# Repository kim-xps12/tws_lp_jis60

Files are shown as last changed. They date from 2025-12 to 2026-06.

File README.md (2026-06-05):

# tws_lp_jis60

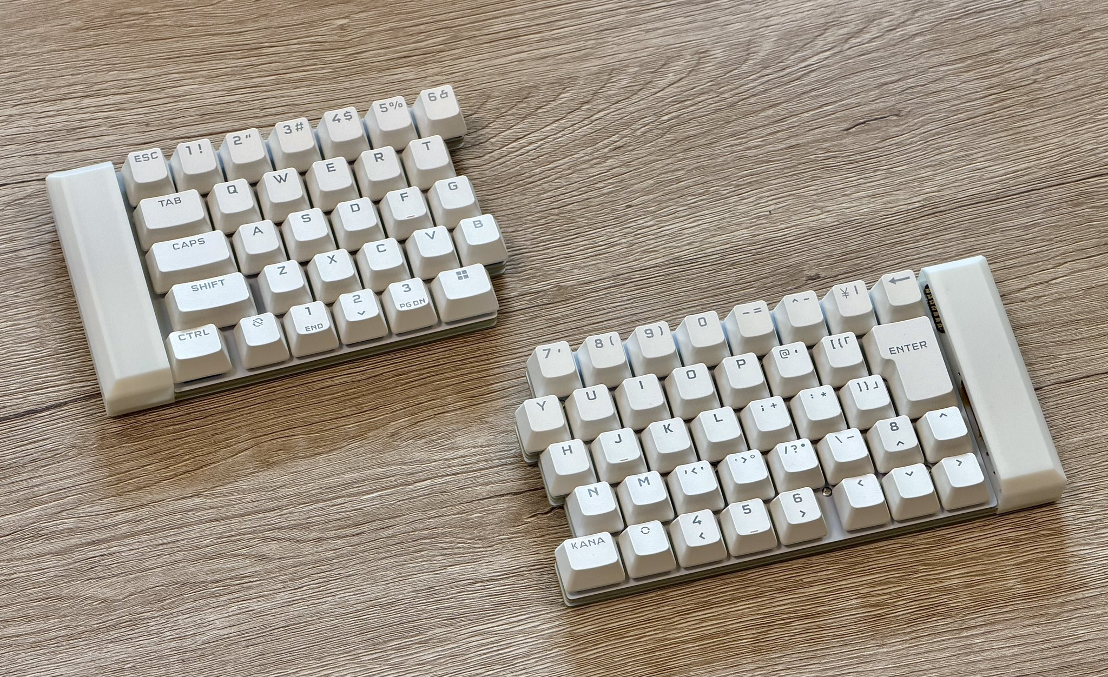
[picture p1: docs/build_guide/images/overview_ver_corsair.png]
完成品の写真


## About

JIS配列・ロープロファイル・完全無線の左右分割60%キーボードです。

## Concept

[sphh jp v2 (a bit keys)](https://abitkeys.com/sphhjp/build_v2.html) のHHKB-likeなJIS配列を分割化したコンセプトを継承し、完全無線化とロープロファイル化を加えた設計です。

- JIS 60%配列（ISOエンター、矢印キー付き）
- 完全無線（PC接続も左右間もBLE）
- Kailh Choc v2 互換ホットスワップ
- PCBサンドイッチ構造
- ZMK Firmware によるキーマップ変更
- XIAO nRF52840 搭載

設計の詳細は設計者の note 記事を参照してください: [JIS配列でロープロファイルな完全無線の左右分割キーボードを作った話](https://note.com/b_sky_lab/n/n9fbacc2c5264)

## How to Build

ビルドガイドは Web 版（[https://b-sky-lab.github.io/tws_lp_jis60/](https://b-sky-lab.github.io/tws_lp_jis60/)）を参照してください。ソースは [docs/build_guide/build_guide.md](docs/build_guide/build_guide.md) です。

ファームウェア（ZMKシールドモジュール）は [b-sky-lab/tws_lp_shield_module](https://github.com/b-sky-lab/tws_lp_shield_module) で管理されています。

## Where to Get

<!-- TODO: Booth頒布開始後にリンクを追加 -->
準備中

## License

このリポジトリは CC-BY-SA-4.0（Creative Commons Attribution-ShareAlike 4.0 International）でライセンスされています．

詳細は [LICENSE](./LICENSE) を参照してください.

### Third-Party Components

本プロジェクトは，以下の第三者ライブラリのコンポーネントを利用しています：

#### 1. OPL_Kicad_Library (CC-BY-SA-4.0)
- fork元: https://github.com/Seeed-Studio/OPL_Kicad_Library
- fork先: https://github.com/kim-xps12/OPL_Kicad_Library
- ライセンス: CC-BY-SA-4.0
- 変更ファイル: `XIAO-nRF52840-DIP.kicad_mod`（DRCシルク警告の修正）
- 利用箇所: [pcb_data/kicad_library/external/OPL_Kicad_Library](pcb_data/kicad_library/external/OPL_Kicad_Library)（submodule）

#### 2. KiCAD_FootPrint (MIT)
- fork元: https://github.com/Salicylic-acid3/KiCAD_FootPrint
- fork先: https://github.com/kim-xps12/KiCAD_FootPrint
- ライセンス: MIT
- 変更ファイル: `Diode_TH_SMD.kicad_mod`（DRCシルク警告の修正）
- 利用箇所: [pcb_data/kicad_library/external/KiCAD_FootPrint](pcb_data/kicad_library/external/KiCAD_FootPrint)（submodule）

#### 3. MX_V2 (MIT)
- fork元: https://github.com/ai03-2725/MX_V2
- 利用ディレクトリ:[custom-library.pretty](pcb_data/kicad_library/custom-library.pretty)
- ライセンス: MIT
- 派生物: `pcb_data/kicad_library/custom-library.pretty/`内のカスタムフットプリント
- 帰属表示: 当該ディレクトリ内の[LICENSE_MX_V2.txt](pcb_data/kicad_library/custom-library.pretty/LICENSE_MX_V2.txt)を参照

### Why CC-BY-SA-4.0？

本作のライセンスがCC-BY-SA-4.0である理由は，PCB設計ファイルにOPL_Kicad_Libraryから改変したフットプリントを組み込んでいるからです．CC-BY-SA-4.0のShareAlike条項により，派生物も同じCC-BY-SA-4.0ライセンスを継承する必要があります．

MITライセンスのコンポーネント（KiCAD_FootPrint，MX_V2）は，適切な帰属表示を維持することでCC-BY-SA-4.0と互換性があります．

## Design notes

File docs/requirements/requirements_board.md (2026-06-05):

# 基板の要件

本書では自作左右分割キーボード`tws_lp_jis60`の基板設計に対して求める要件を列挙する．

## 機械的要件

- キースイッチの数，キー幅，配置の全てをsphh jp v2に準拠すること．
- 基板の外形をsphh jp v2に準拠した形状とすること．すなわち，左手側基板の右辺以外3辺と右手側基板の左辺以外3辺は水平/垂直な線であり，左手側基板の右辺と右手側基板の左辺はそれぞれが噛み合うような階段状の形状が求められる．
- （参考）sphh jp v2公式サイト: https://abitkeys.com/sphhjp/build_v2.html

## 電子回路要件

### キースイッチ

- キースイッチのホットスワップに対応するため，基板にはソケットのみを半田付けで固定すること．
- 対象のキースイッチは，Kailh Choc v2互換を想定すること．

### マイコン

- マイコンにはxiao系の開発ボードを用いること．
  - XIAO nRF52840 を採用（BLE対応・バッテリー管理IC搭載のため）  
- 開発ボードは基板に取り付けること．
  - **実装**: XIAO nRF52840 を基板に直接はんだ付け（着脱不可）
- ボード選定の際には最低限以下を満たすこと．

  - キー数に対して十分な入出力ピンを持つこと
  - 単体でバッテリ管理機能を搭載していること
  - 単体でBluetooth LEによる通信が行えること
  - 接続端子としてUSB Type-Cを有すること

- 上記以外にも基板レイアウト等に対して適切な条件を適宜定めること．

### インジケータ

- キーボードの内部状態（現在のBT接続状態，電池残量など）を示すためのインジケータランプを有すること．
  - **実装**: XIAO nRF52840 オンボードのRGB LED 1個を使用し、[zmk-rgbled-widget](https://github.com/caksoylar/zmk-rgbled-widget) により色と点滅パターンで接続状態・電池残量・レイヤーを表示
- 適切な色のLEDの点灯状態によって上記を示すことを最小要件とする．

### 電源

- 左右の基板にはそれぞれ独立した電源が取り付けられること
- 使用される電力源は乾電池が最も好ましいが，開発難易度に応じてマイコンボードに直接接続できる充電池を用いてもよい．
  - **実装**: リチウムイオンポリマーバッテリーをXIAO nRF52840のBATパッドに直接接続（内蔵充電IC BQ25101で管理）

### 接続方式

- 通常の使用においてホストマシン（PC, スマートフォン等）との接続にはBluetooth LEを用いること．
- 左右間の通信も無線で行うこと．この接続はファームウェアの機能を適切に利用する想定でよい．
- ただし，キーマップ書き換え時にはマイコンボードに搭載されたUSBポートを利用することを想定してもよい．

## ソフトウェア要件

- ファームウェアのベースとしてZMK Firmwareを用いること
- ファームウェア書き換えによってキーマップの変更ができること
- （参考）
    - ZMK Firmware公式ページ: https://zmk.dev/docs

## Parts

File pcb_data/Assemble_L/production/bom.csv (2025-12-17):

Designator | Footprint | Quantity | Value | LCSC Part #
D0-1, D0-2, D0-3, D0-4, D1-0, D1-2, D1-3, D1-4, D2-0, D2-1, D2-3, D2-4, D3-0, D3-1, D3-2, D3-4, D4-0, D4-1, D4-2, D4-3, D5-0, D5-1, D5-2, D5-3, D5-4, D6-0, D6-1, D6-2, D6-3, D6-4, D6-5, DI0, DI1, DI2, DI3, DI4, DI5, DS0, DS1, DS2, DS3, DS4, DS5 | Diode_TH_SMD | 43 | 1N4148W
RC0-1 | Kailh-PG1353-Hotswap-L-1.5U | 1 | SW_Push
RC0-2 | Kailh-PG1353-Hotswap-L-1.75U | 1 | SW_Push
RC0-3 | Kailh-PG1353-Hotswap-L-2U | 1 | SW_Push
RC0-4, RC1-0, RC1-2, RC1-3, RC1-4, RC2-0, RC2-1, RC2-3, RC2-4, RC3-0, RC3-1, RC3-2, RC3-4, RC4-0, RC4-1, RC4-2, RC4-3, RC5-0, RC5-1, RC5-2, RC5-3, RC5-4, RC6-0, RC6-1, RC6-2, RC6-3, RC6-4 | Kailh-PG1353-Hotswap-L-1U | 27 | SW_Push
RC6-5 | Kailh-PG1353-Hotswap-L-1.25U | 1 | SW_Push
U1 | XIAO-nRF52840-DIP | 1 | XIAO-nRF52840

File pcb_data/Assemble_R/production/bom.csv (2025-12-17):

Designator | Footprint | Quantity | Value | LCSC Part #
D0-10, D0-11, D0-12, D0-13, D0-8, D0-9, D1-10, D1-11, D1-12, D1-7, D1-9, D2-10, D2-11, D2-12, D2-13, D2-7, D2-8, D3-11, D3-12, D3-13, D3-7, D3-8, D3-9, D4-10, D4-12, D4-7, D4-8, D4-9, D5-10, D5-11, D5-13, D5-7, D5-8, D5-9, D6-10, D6-11, D6-12, D6-8, D6-9, DI10, DI11, DI12, DI13, DI7, DI8, DI9, DS10, DS11, DS12, DS13, DS7, DS8, DS9 | Diode_TH_SMD | 53 | 1N4148W
RC0-10, RC0-11, RC0-12, RC0-8, RC0-9, RC1-10, RC1-11, RC1-12, RC1-7, RC1-9, RC2-10, RC2-11, RC2-12, RC2-13, RC2-7, RC2-8, RC3-11, RC3-12, RC3-13, RC3-7, RC3-8, RC3-9, RC4-10, RC4-12, RC4-7, RC4-8, RC4-9, RC5-10, RC5-11, RC5-13, RC5-7, RC5-8, RC5-9, RC6-11, RC6-12, RC6-8, RC6-9 | Kailh-PG1353-Hotswap-R-1U | 37 | SW_Push
RC0-13 | Kailh-PG1353-Hotswap-R-1.25U | 1 | SW_Push
RC6-10 | Kailh-PG1353-Hotswap-ISOEnter-R | 1 | SW_Push
U1 | XIAO-nRF52840-DIP | 1 | XIAO-nRF52840

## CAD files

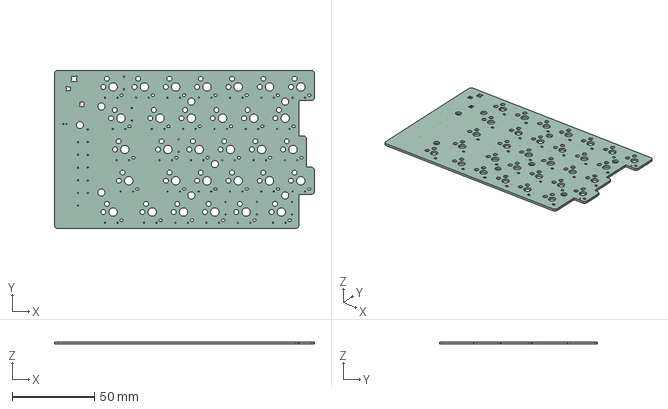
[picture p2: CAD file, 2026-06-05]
pcb_data/Assemble_L/Assemble_L.step
158.4 x 96.4 x 1.51 mm

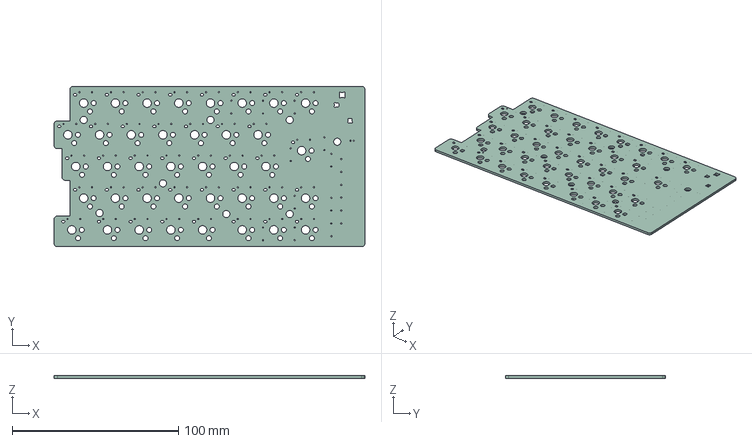
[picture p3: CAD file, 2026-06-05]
pcb_data/Assemble_R/Assemble_R.step
186.9 x 96.4 x 1.51 mm

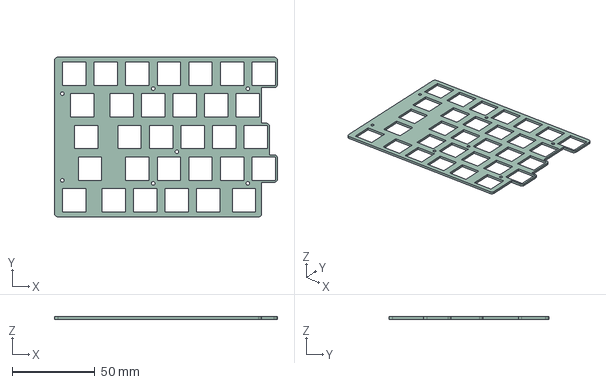
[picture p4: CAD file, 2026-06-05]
pcb_data/Top_L/Top_L.step
134.5 x 96.4 x 1.51 mm

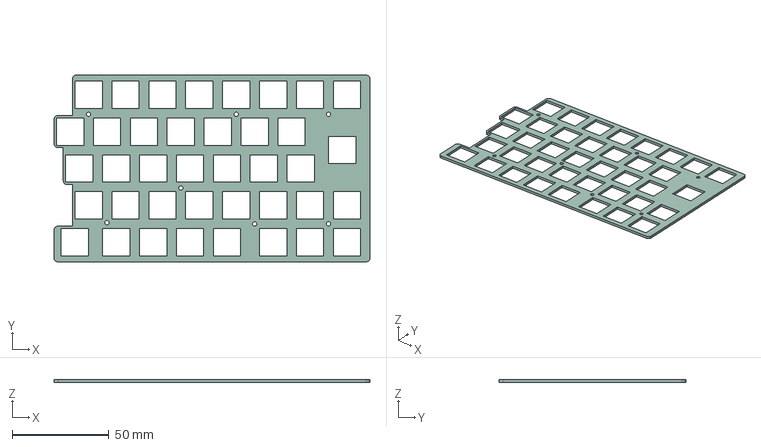
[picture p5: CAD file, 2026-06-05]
pcb_data/Top_R/Top_R.step
163.1 x 96.4 x 1.51 mm

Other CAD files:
pcb_data/Bottom_L/Bottom_L.step
pcb_data/Bottom_R/Bottom_R.step

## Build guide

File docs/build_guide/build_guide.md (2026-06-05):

# Tws-lp-jis60 ビルドガイド

完成写真
(※ 画像はコルセアの既製品キーキャップを使用しています)

## 0. 本ガイドについて

- 対象キット: `tws_lp_jis60`（JIS配列・ロープロファイル・完全無線・左右分割60%キーボード）
- 設計: [b-sky-lab/tws_lp_jis60](https://github.com/b-sky-lab/tws_lp_jis60), B-SKY Lab
- 想定読者: はんだ付け経験のある方
- 前提知識: 表面実装はんだ付けの基本，PCの基本操作
- ライセンス: 本キットおよびガイドは CC-BY-SA-4.0でライセンスされています
- 本ガイドの一部販売リンクにはAmazonアソシエイト・リンクが含まれます．

> [!CAUTION]
> **リチウムイオンポリマーバッテリーの安全な取り扱いに関する警告**
>
> 本キットはリチウムイオンポリマーバッテリー（以降，リポバッテリー）を使用します．リポバッテリーは取り扱いを誤ると **発火・爆発の危険** があります．
>
> - **+/- を間違えない**
> - **短絡（ショート）させない**
> - **針や鋭利なもので刺さない**
> - **過充電・過放電させない**
> - **膨らみ・変色・異臭・その他の違和感** を感じたら即座に使用を中止する
> - はんだごてをバッテリー本体に近づけない
> - 不要になったバッテリーの廃棄方法は各自治体の指示に従う

## 1. はじめに

### 1.1 このキーボードの特徴

`tws_lp_jis60` は **JIS配列・ロープロファイル・完全無線** の60%左右分割キーボードです．[sphh jp v2 (a bit keys)](https://abitkeys.com/sphhjp/build_v2.html) にインスパイアされています．

- **JIS 60% 配列**: ISOエンター，矢印キー，`かな` などのJIS変換キーを備え，広く一般的なJIS配列の操作感に近いまま分割キーボードに移行できます．
- **完全無線**: キーボードとPCの間および左右間の両方をBLEで接続．ケーブル一切なしでデスクをすっきり保てます．
- **ロープロファイル**: Kailh Choc v2 互換スイッチを採用し，手首への負担が少ない打鍵姿勢を実現．
- **ホットスワップ対応**: スイッチを後から差し替え可能．はんだ付けはせず気軽にカスタムできます．

### 1.2 本ガイドで扱うこと

本ガイドは，次の作業を順に説明します．

1. キットの内容確認と別途用意するものの調達（2章）
2. はんだ付け作業（4章，最も時間がかかる工程）
3. プレートとケースの組み立て（5章）
4. ZMKファームウェアの書き込みと動作確認（6〜7章）
5. トラブルが起きたときの対処（8章）

### 1.3 さらに詳しい背景

設計者の開発記録は note 記事で公開されています．設計思想や試作版からの改修経緯に興味がある方は併読をおすすめします．

- [JIS配列でロープロファイルな完全無線の左右分割キーボードを作った話](https://note.com/b_sky_lab/n/n9fbacc2c5264)（孔明@B-SKY Lab）

---

## 2. キット内容物・別途用意するもの

作業を始める前に，キットに含まれているもの／別途用意が必要なものを確認します．

### 2.1 キット同梱物
本キットには6枚の基板と2個のバッテリーカバーの計8つの部品が含まれています．詳細を次表および次図に示します．

| 部品 | 数量 |
|---|---|
| トッププレート（左） | 1 |
| トッププレート（右） | 1 |
| メイン基板（左） | 1 |
| メイン基板（右） | 1 |
| ボトムプレート（左） | 1 |
| ボトムプレート（右） | 1 |
| バッテリーカバー（左右共通） | 2 |

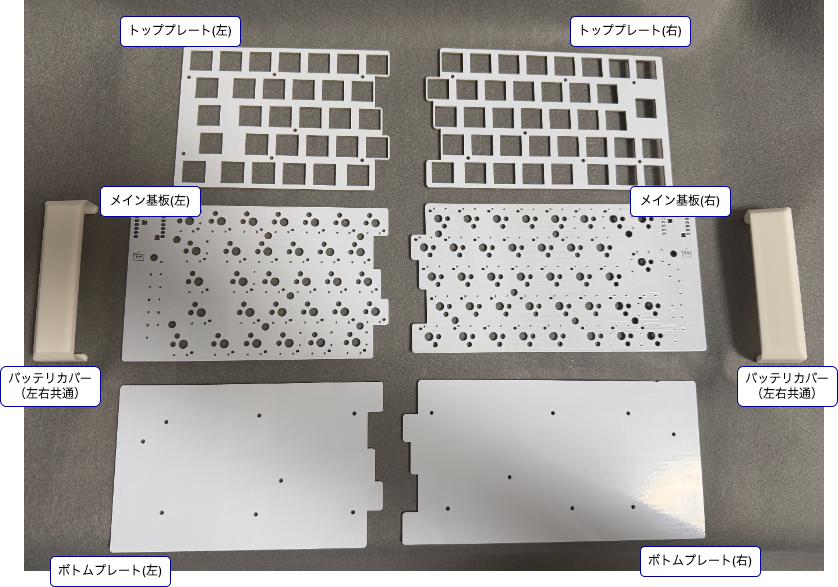
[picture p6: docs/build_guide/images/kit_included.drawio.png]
キット同梱物


実際にキットを開封したら上記の数が揃っているか確認し，不足があれば購入元へご連絡ください．

### 2.2 別途用意するもの

本キットを製作するためには，以下の部品を別途ご用意いただく必要があります．

| 部品 | 数量 | 購入先・備考 |
|---|---|---|
| 1N4148W ダイオード | 96個 | [shop.yushakobo](https://shop.yushakobo.jp/products/a0800di-02-100) |
| Kailh Choc ホットスワップソケット | 70個 | [shop.yushakobo](https://shop.yushakobo.jp/products/a01ps?_pos=2&_sid=8127579c4&_ss=r&variant=37665172553889) |
| スリムヘッドネジ M2 x 4mm | 28本 | [shop.yushakobo](https://shop.yushakobo.jp/products/a0800s2?variant=37665432502433) |
| 丸スペーサ M2 x 5mm | 28本 | [shop.yushakobo](https://shop.yushakobo.jp/products/a0800c2?variant=37665435156641) |
| XIAO nRF52840 | 2 | [shop.yushakobo](https://shop.yushakobo.jp/products/11442) |
| Kailh Choc v2 互換キースイッチ | 70 | 例:  [shop.yushakobo](https://shop.yushakobo.jp/products/9681)（お好みのスイッチをお使いください） |
| Kailh Choc v2 互換対応キーキャップ | 1セット | 例: CORSAIR PBT DOUBLE-SHOT CH-9911040-JP （お好みのキーキャップをお使いください）|
| リチウムイオンポリマー電池 3.7V 300mAh | 2 | [せんごくネット通販](https://www.sengoku.co.jp/mod/sgk_cart/detail.php?code=EEHD-5GHG) |
| PHコネクター ベース付ポスト トップ型 2P B2B-PH-K-S | 2 | [秋月電子通商](https://akizukidenshi.com/catalog/g/g112802/) |
| USB Type-C ケーブル | 1 | ファーム書き込み時に使用．データ通信対応のもの |
| 両面テープ | 適量 | リポバッテリーの固定用，例: [(amazon)3M スコッチ はがせる 透明 両面テープ](https://amzn.to/4dMHgQM) |
| ゴム足 | 適量 | 例: [(amazon)ゴム足(12個)粘着式 MF-RUBF12](https://amzn.to/4o9MQA0) |
| 滑り止めシート | 適量 | 例: [(amazon)GRIPLU グレー](https://amzn.to/4ept1Bz) |
### 2.3 必要工具

| 工具 | 用途・備考 |
|---|---|
| はんだごて | 温度調整式 ＋ ILS型の極細小手先を推奨．例: [秋月電子通商, 温度調整機能付USB接続はんだこて T65](https://akizukidenshi.com/catalog/g/g118315/) + [秋月電子通商, 替こて先 T65用 ILS](https://akizukidenshi.com/catalog/g/g118318/) |
| はんだ | 0.6mm径程度を推奨．例: [秋月電子通商, スズ60％ 鉛入りはんだ Φ0.6mm](https://akizukidenshi.com/catalog/g/g130184/) |
| こて台 | 例: [秋月電子通商, こて台 FH300-81](https://akizukidenshi.com/catalog/g/g114458/) |
| ドライバー | 例: [秋月電子通商, DM-60 精密ドライバーセット](https://akizukidenshi.com/catalog/g/g118343/) |
| テスター | 例: [秋月電子通商, デジタルマルチメーター DT83B](https://akizukidenshi.com/catalog/g/g114310/) |
| フラックス | ペン型フラックスを推奨．例: [Amazon, ホーザン H-722-P](https://amzn.to/3S7GFAF) |
| ピンセット | 例: [Amazon, HOZAN P-880](https://amzn.to/4g7HiUG) |
| ニッパー | 例: [Amazon, ANEX No.280](https://amzn.to/4uQkpJX) |
| マスキングテープ | 部品の仮固定用 例: [Amazon 3M M40J-18](https://amzn.to/4e0B5Hx)|

## 3. 作業前の確認

### 3.1 表裏と左右の判別

組み立てへ入る前に，各基板の左右と裏表が分かりやすい状態へラベリングをしておきます．
次の2枚の写真を参考に，マスキングテープ等を貼った上で書き込みを行うのがオススメです（作業の際には適宜剥がしたり移動してください）．

表裏判別_表

表裏判別_表

## 4. 半田付け

本キットの半田付けは以下の順で実施することを推奨します．

1. ダイオード
1. キースイッチソケット
1. XIAO の取り付け（表面実装）
1. リポバッテリー用コネクタの取り付け

### 4.1 ダイオード（1N4148W）の半田付け

チップダイオードには線が刻印されています．この線側が **カソード（K）** 側です．これと基板シルクにあるダイオードの回路図記号にあるカソード側のラインとを揃えて半田付けします．正しい向きの例を次図に示します．

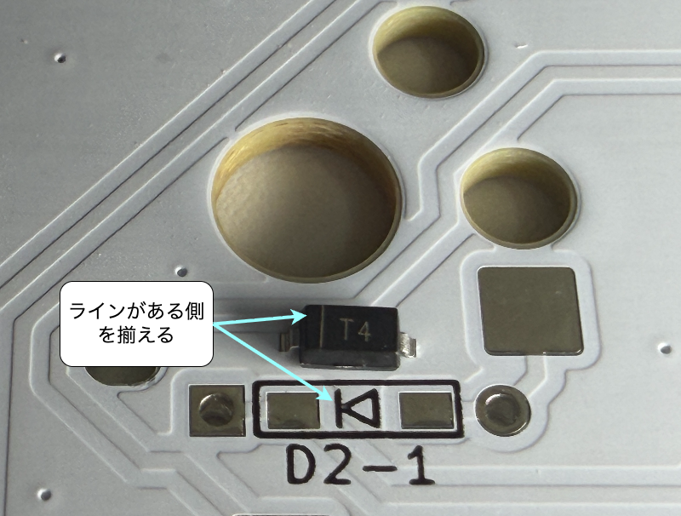
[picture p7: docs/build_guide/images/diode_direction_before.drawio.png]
ダイオードの半田付け向き_取り付け前


ラインを揃えた向きで半田付けします．

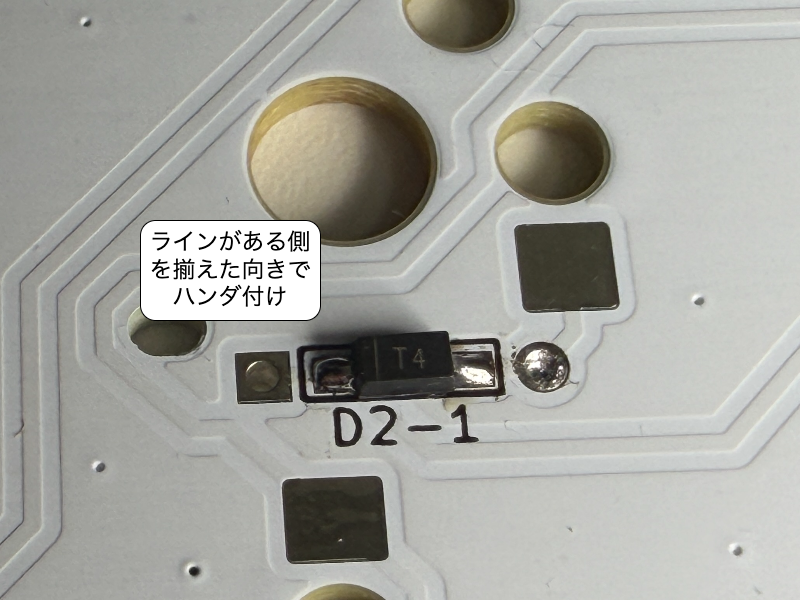
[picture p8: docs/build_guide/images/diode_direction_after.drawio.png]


逆向きに付けると周辺のキーが反応しません．細心の注意を払って取り付けてください．この作業を **両基板全てのダイオードの箇所** へ実施します．

### 4.2 Kailh Choc V2 ホットスワップソケット

全てのダイオードを取り付けたら，キーソケット（Kailh Choc V2 ホットスワップソケット）の取り付けを実施します．取り付けイメージは次図の通りです．

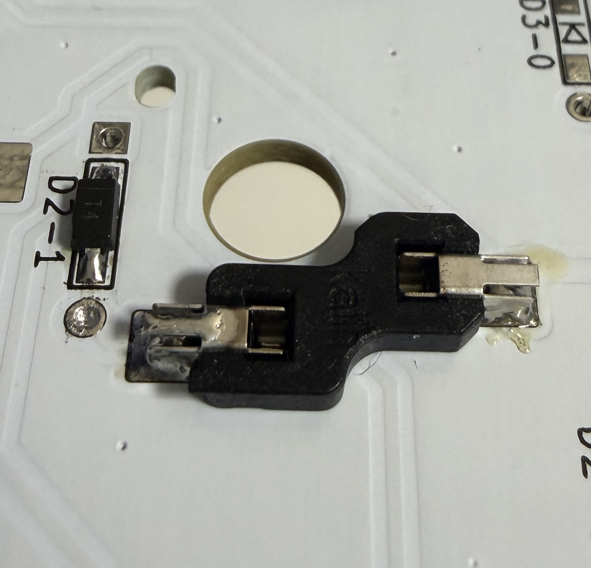
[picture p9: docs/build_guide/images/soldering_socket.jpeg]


この部品の取り付け方は多くの解説記事や動画が公開されているため，詳細はそちらへ譲ります．
「キーソケット　ハンダ付け」等で検索してみてください．

### 4.3 XIAO の取り付け

全てのダイオードおよび全てのキーソケットを取り付けたら，次はXIAO nRF52840をハンダ付けします．本作ではこの部品も基板へ **直接はんだ付け** で取り付けます．
大まかな手順は以下の通りです．

1. 本体基板の表面，XIAO用フットプリント位置に XIAO を載せます．
1. XIAO が基板と平行になっていることを確認し，**対角の1ピンずつ仮はんだ** して位置を固定します．傾いていたらはんだを溶かして修正します．
1. xiao背面のBAT端子と基板端面キャッスルホールを半田付けします．例えば以下の動画が参考になります．他にも様々なやり方があるので「xiao 背面　半田付け」で検索し，自身にあった方法を見つけてみてください．

https://www.youtube.com/watch?v=PIEX10VkBPM

掲載を快諾いただいた[kay(keyFreaks)](https://www.youtube.com/@LiNEA.keyFreaks)様ありがとうございました！

私が実際に半田付けした様子は次図の通りです．

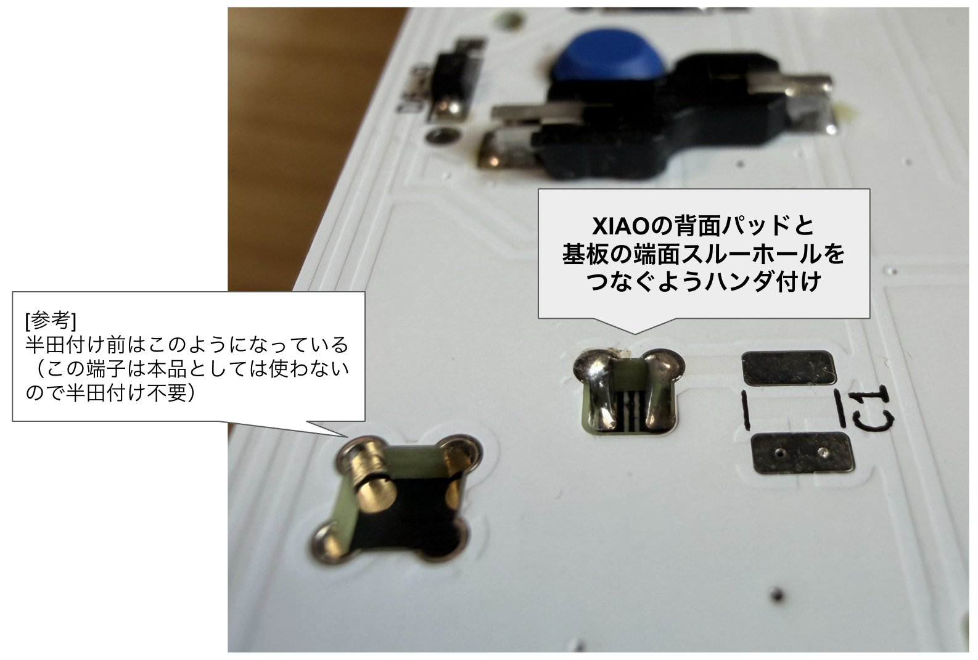
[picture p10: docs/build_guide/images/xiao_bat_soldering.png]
xiao背面半田付けイメージ


**また，C1パッドは実験・拡張用です．無視して問題ありません．**

### 4.4 リポバッテリー用コネクタの取り付け

リポバッテリーは取り扱いを誤ると発火・爆発の危険があります．次の点を厳守してください．

- **+/− を絶対に間違えない**
- 配線中はバッテリーを **絶縁テープで覆う** などしてショートを防止
- 膨らみ・変色・異臭を感じたら即座に使用中止
- はんだごてをバッテリー本体に近づけない

まずはリポバッテリー用のPHコネクタを基板にハンダ付けします．シルクに描かれた切り欠きと実際の刻印を揃えて取り付けます．

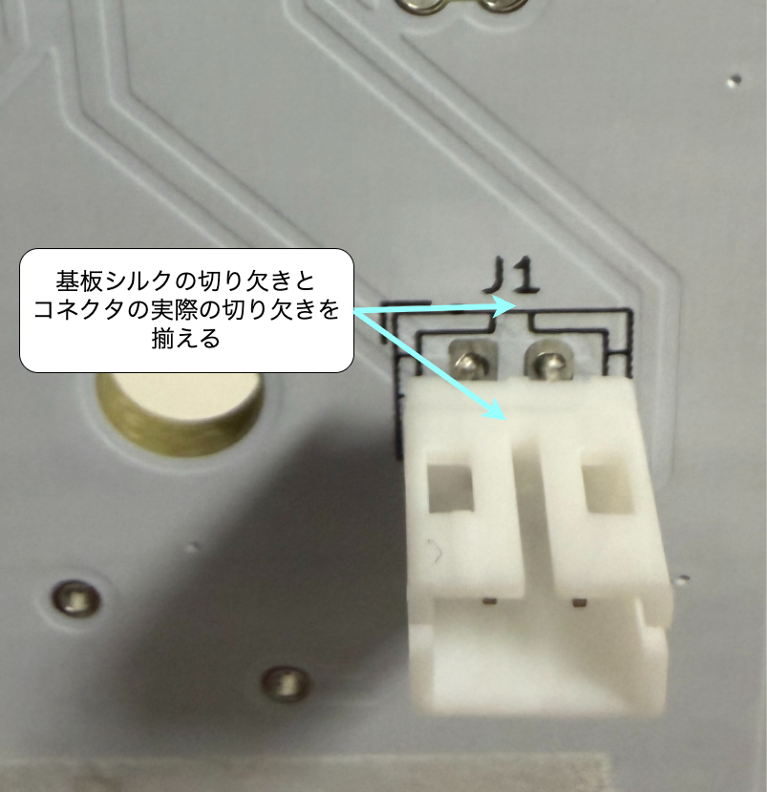
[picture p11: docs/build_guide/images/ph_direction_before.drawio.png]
リポバッテリー用コネクタの取り付け


ここで，リポバッテリーを取り付けた時に **次図の向きで左側がプラス極（赤），右側がマイナス極（黒）** に接続されることを確認します．誤りがある場合，機器の破損，発火，爆発等の危険があります．必ず確認してください．

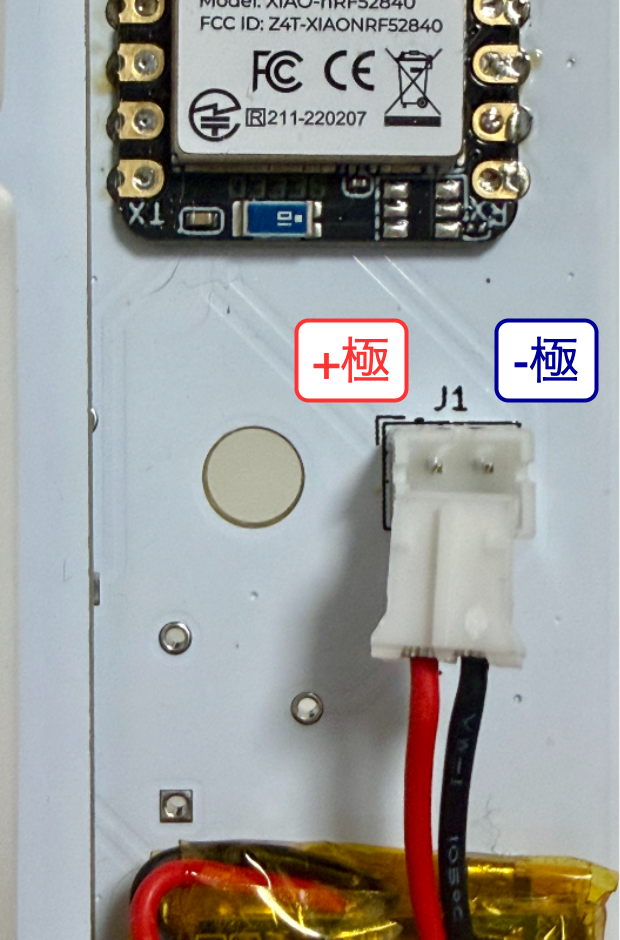
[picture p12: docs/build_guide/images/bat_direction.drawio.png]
リポバッテリーの極性確認


ハンダ付が全て完了し問題なければ「5. 組み立て」に進みます．

## 5. 組み立て

はんだ付けが終わったら，上下プレートで基板を挟む **サンドイッチ構造** に組み立てます．

### 5.1 構成

本キーボードは次の3層構造です．

- **トッププレート**: スイッチ取付穴のあるプレート
- **メイン基板**: スイッチソケット・ダイオード・XIAOが載る基板
- **ボトムプレート**: ボディ底面に相当するプレート

### 5.2 トッププレートとスペーサの締結

次図を参考に，左右トッププレートへ丸スペーサをスリムヘッドネジで固定します．
左右それぞれで7箇所ずつねじ止めします．

左側: 
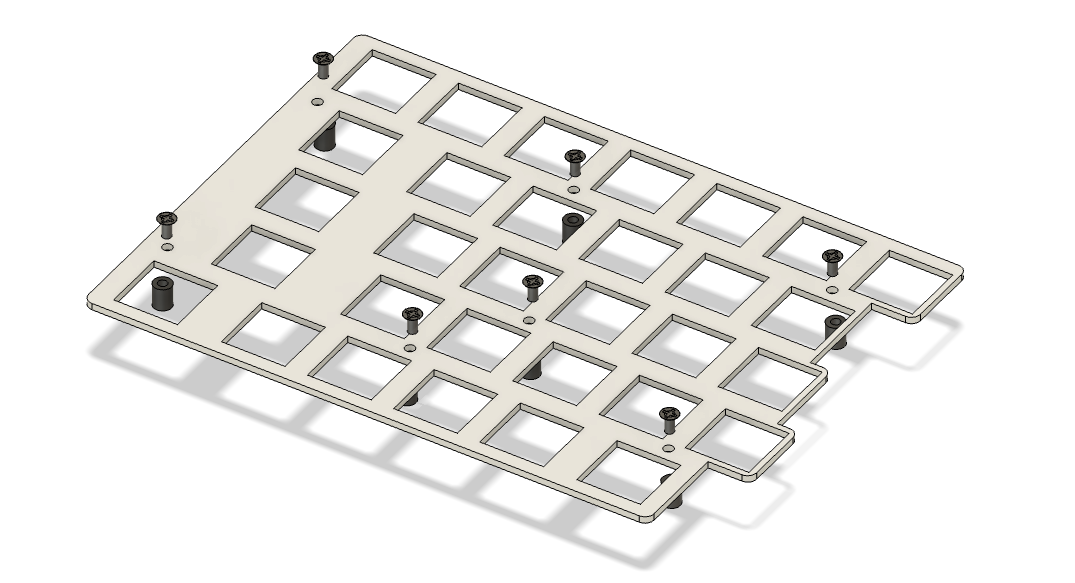
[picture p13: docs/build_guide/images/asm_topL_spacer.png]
トッププレート左とスペーサの締結


右側: 
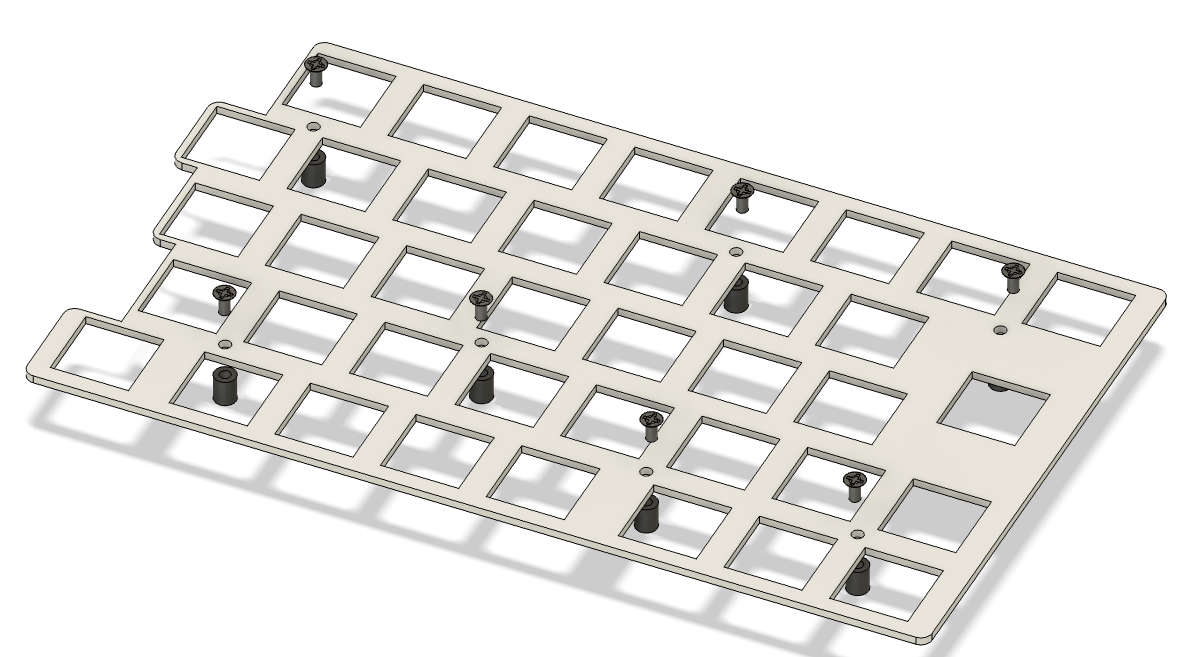
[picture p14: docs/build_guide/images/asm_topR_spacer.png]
トッププレート右とスペーサの締結


### 5.3 メイン基板の挟み込み＋ボトムプレートの締結

トッププレートに締結した丸スペーサをメイン基板の丸穴を通すように重ね合わせることでメイン基板を挟み込み，ボトムプレート側からスリムヘッドネジで締結します．

左側: 
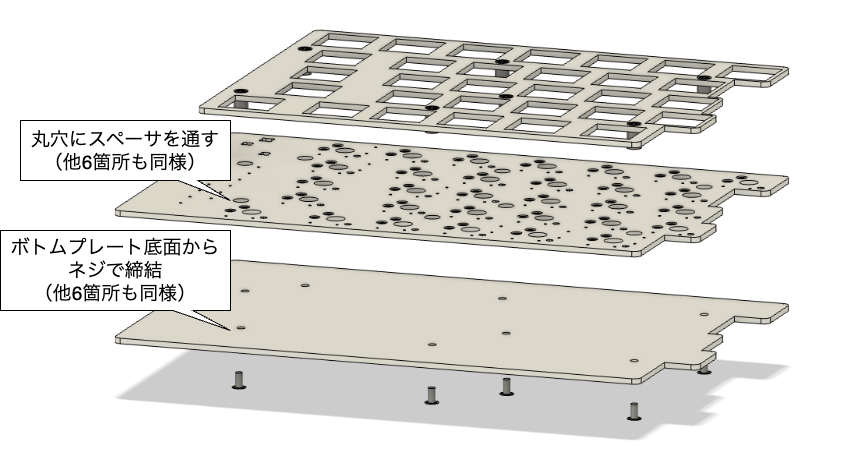
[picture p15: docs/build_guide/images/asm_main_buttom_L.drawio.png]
メイン基板左の挟み込みとボトムプレートの締結


左側を固定し終えた様子: 
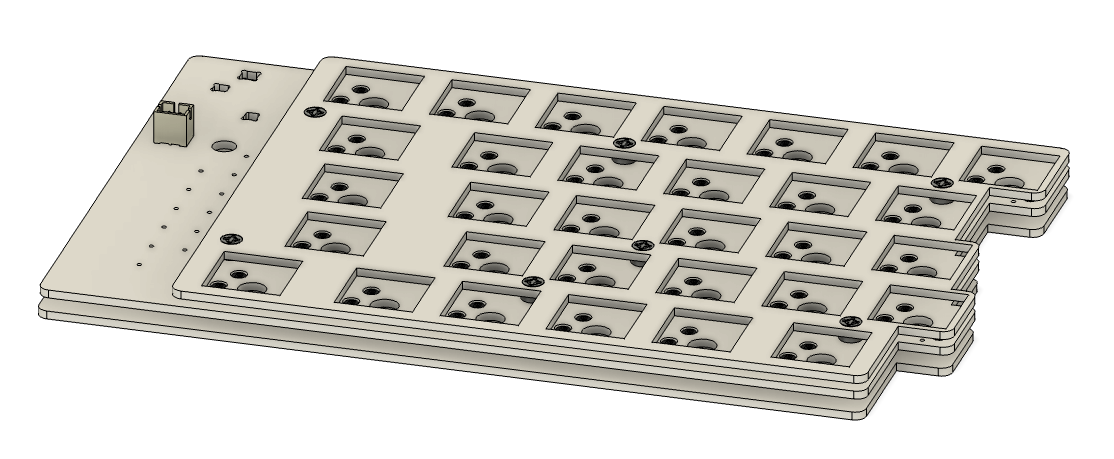
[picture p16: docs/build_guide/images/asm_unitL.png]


右側: 
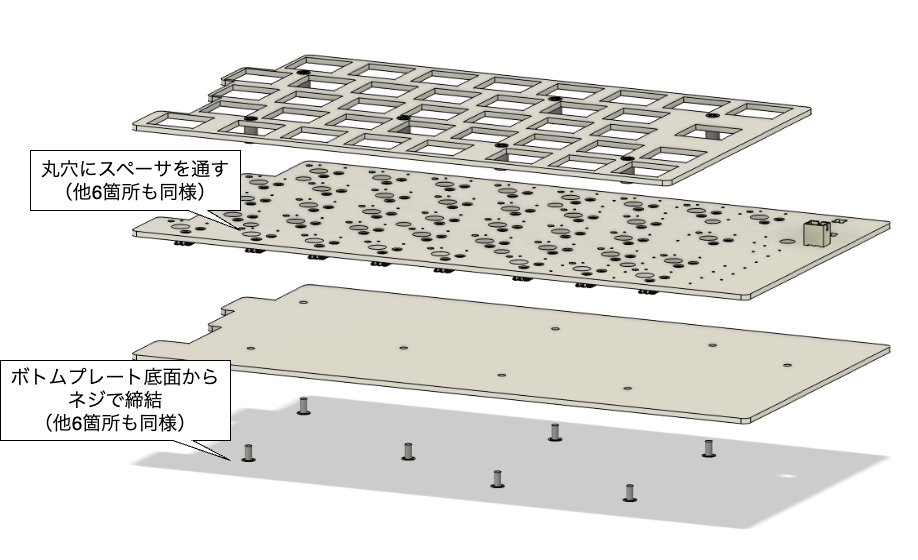
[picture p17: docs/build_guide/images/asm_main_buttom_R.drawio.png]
メイン基板右の挟み込みとボトムプレートの締結


右側を固定し終えた様子: 
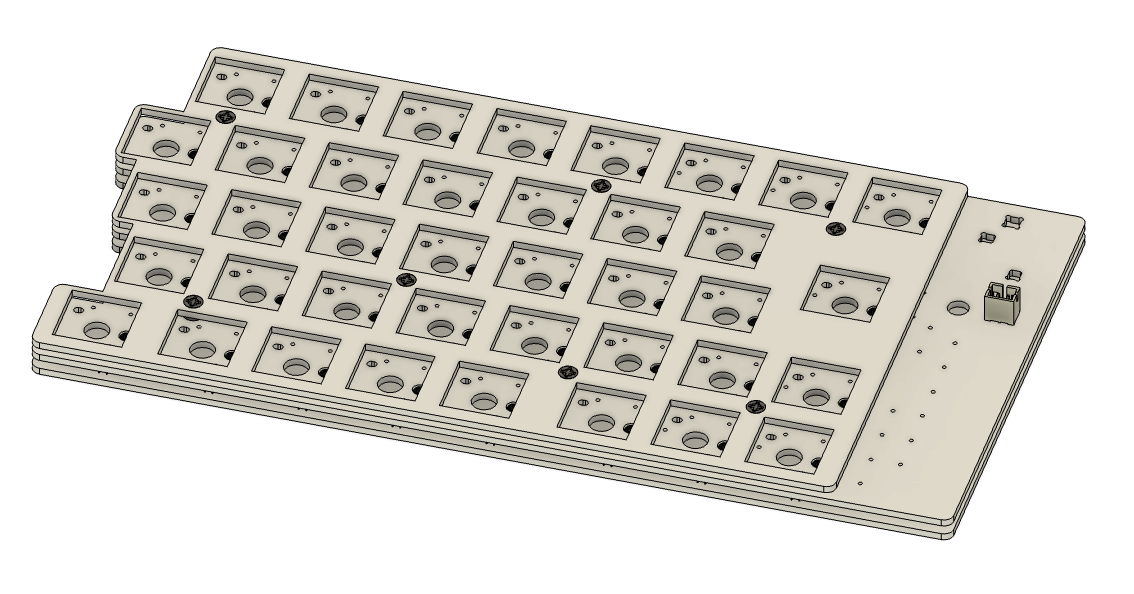
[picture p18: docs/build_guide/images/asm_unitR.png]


### 5.4 キースイッチの取り付け

左右の各プレートを締結したら，キースイッチを取り付けます．トッププレートの上からキースイッチを押し込んで固定します．

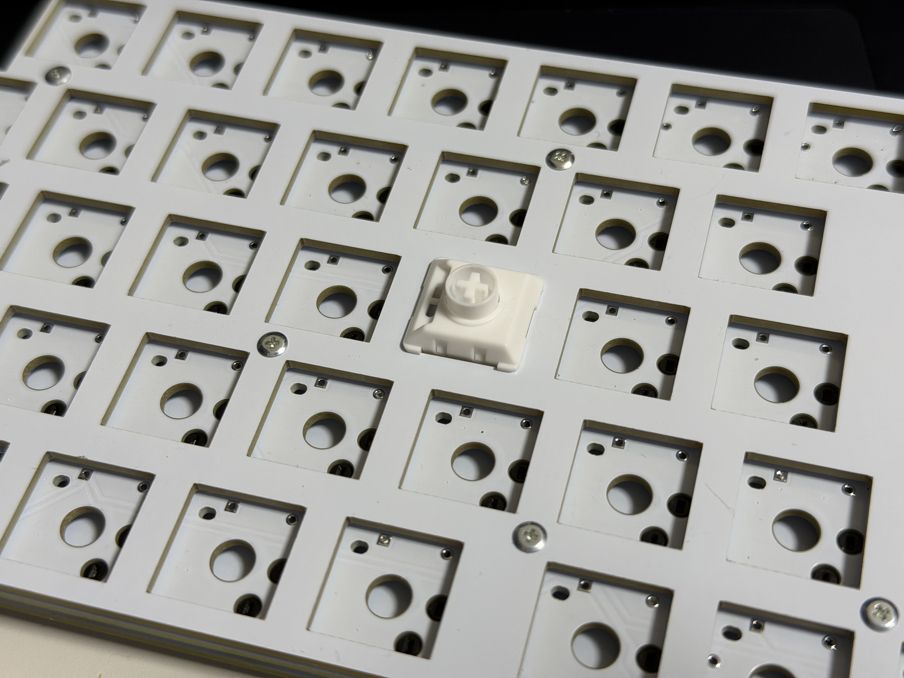
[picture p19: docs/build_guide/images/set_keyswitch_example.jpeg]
キースイッチの取り付けイメージ


左右それぞれに全てキースイッチを取り付けた状態を次図に示します．

左側:
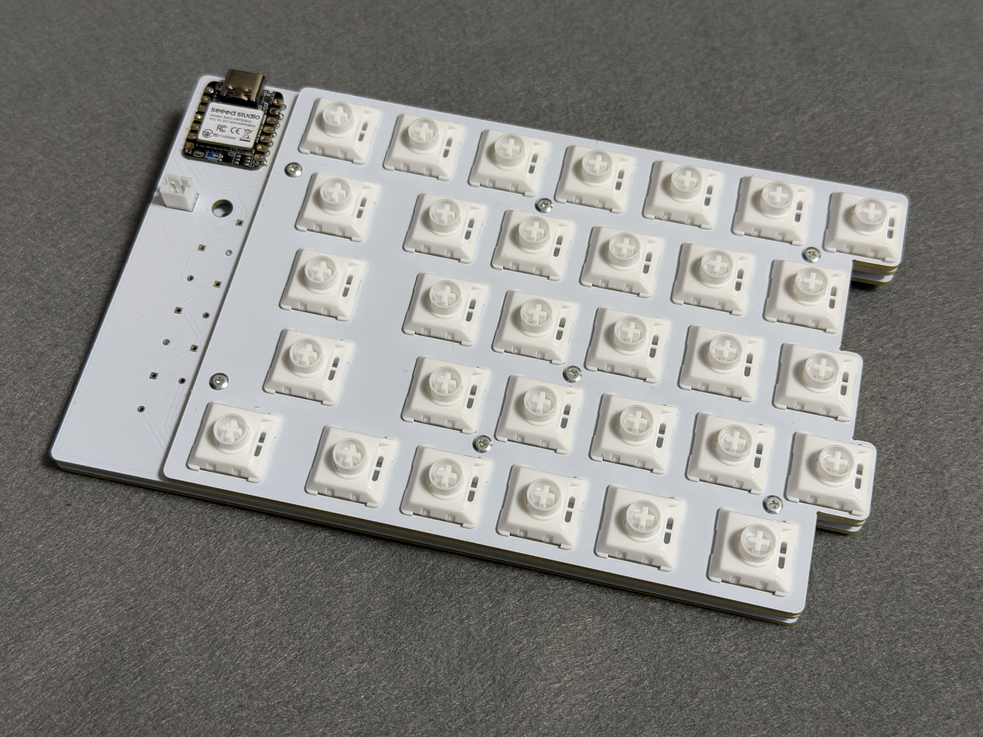
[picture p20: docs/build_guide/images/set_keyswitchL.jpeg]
キースイッチの取り付けイメージ左


右側:
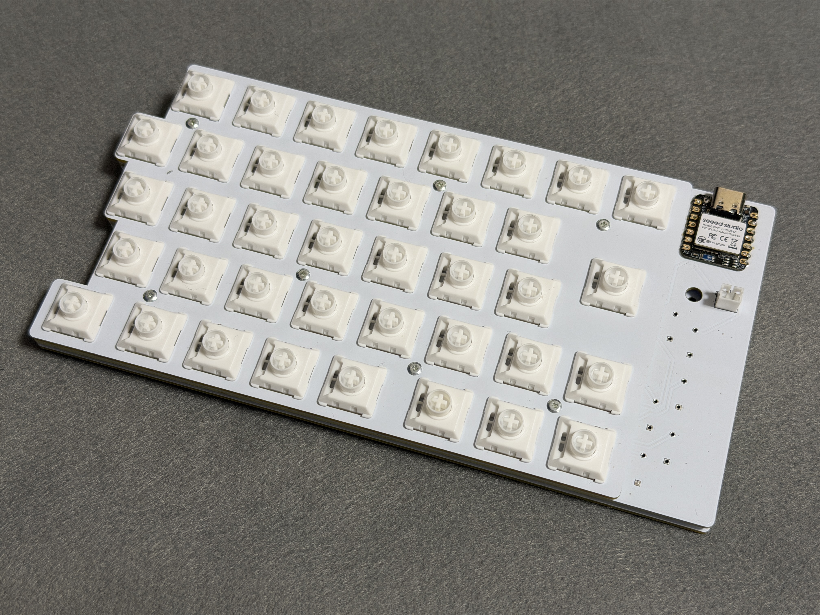
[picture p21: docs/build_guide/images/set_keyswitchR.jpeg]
キースイッチの取り付けイメージ右


### 5.5 キーキャップの取り付け

キースイッチが取り付けられたら，キーキャップを装着します．
本キーボードのデフォルトファームウェア（後述）では，以下のキー配列を想定しています．
（写真の都合でバッテリーカバーが既に取り付け済みになっていますが一旦無視ししてください，後述で出てきます...）

左側: 
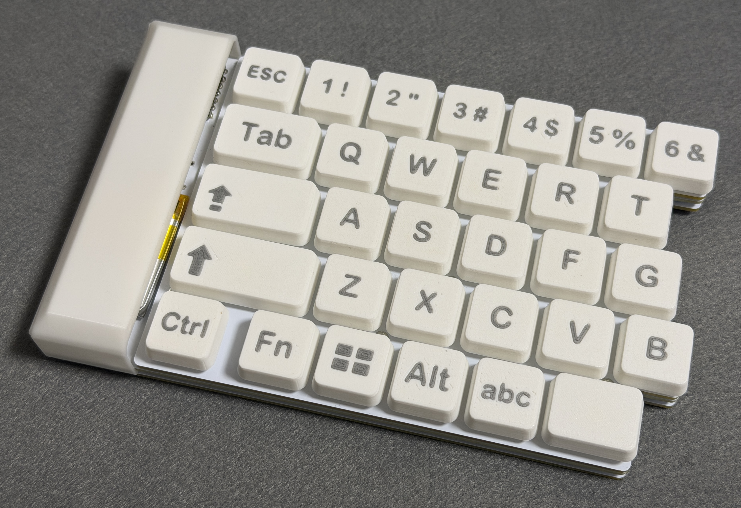
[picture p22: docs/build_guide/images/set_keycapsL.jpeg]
左側キーキャップ取り付け


右側: 
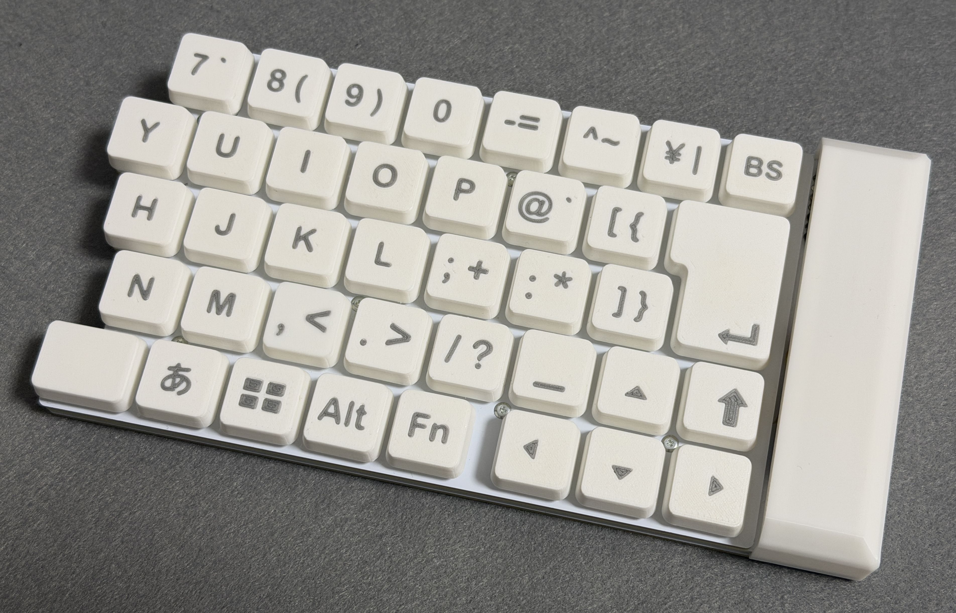
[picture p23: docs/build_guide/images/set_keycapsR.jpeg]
右側キーキャップ取り付け


動作確認後はぜひお好みの配列にカスタムもお試しください．

### 5.6 バッテリーの貼り付け

最後にリポバッテリーを両面テープで固定します．次図のように両面テープを準備して，

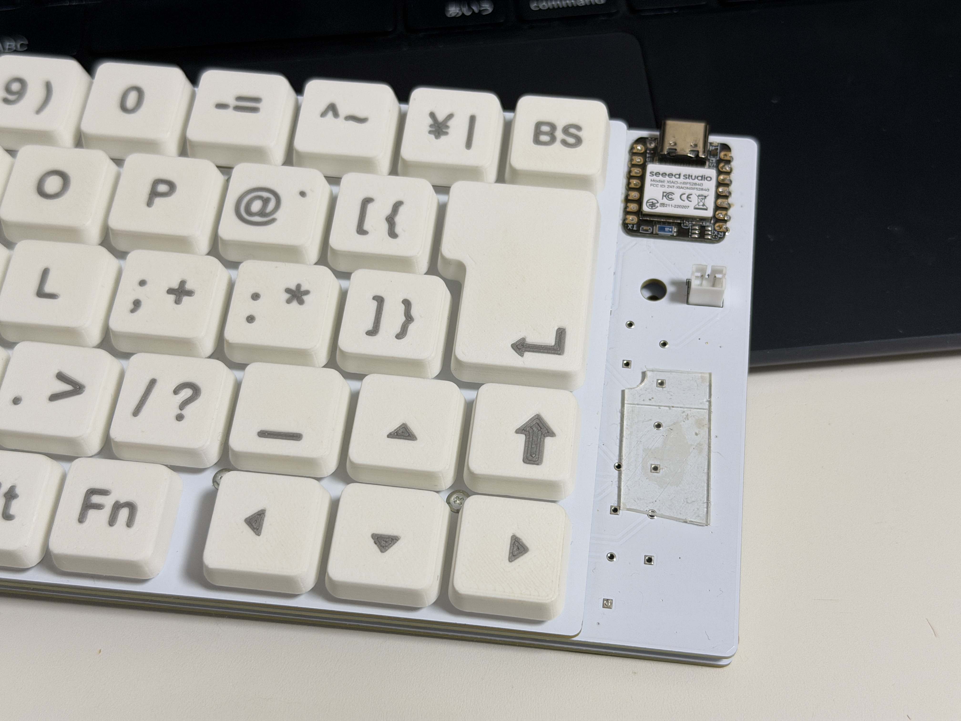
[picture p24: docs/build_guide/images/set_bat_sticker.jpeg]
両面テープ


バッテリ本体を貼り付けます．

ここで，**ケーブルを差し込む前に極性が正しいかを最終確認** してください．

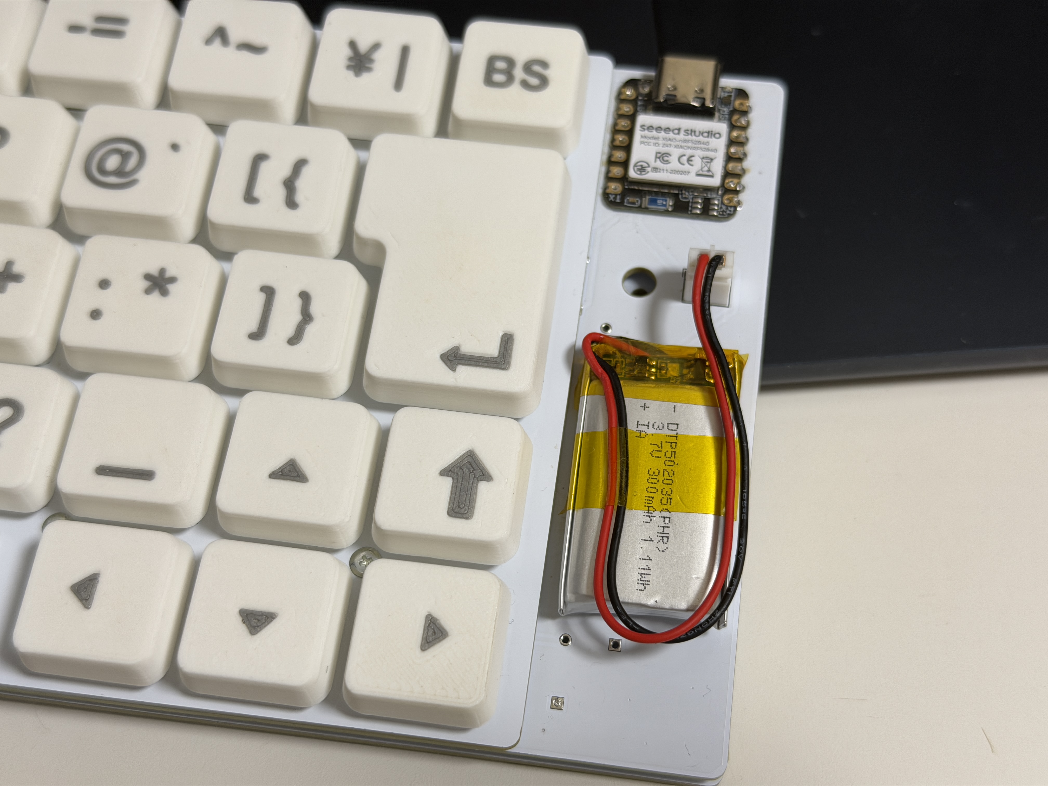
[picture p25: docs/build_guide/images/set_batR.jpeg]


xiaoのLEDが点灯または点滅したら成功です．

反対側も同様に貼り付けます．
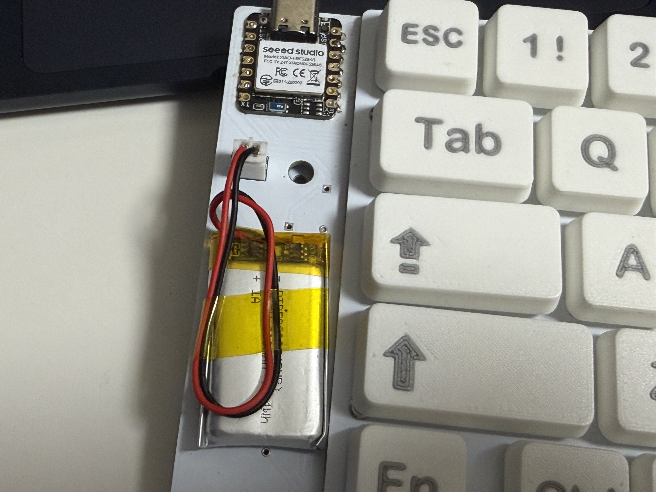
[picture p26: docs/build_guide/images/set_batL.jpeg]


完成したら，ファームウェアの書き込みに進みます（6章）．

### 5.7 バッテリーカバーの取り付け

以下の図を参考にバッテリーカバーをスライドさせて取り付けます．

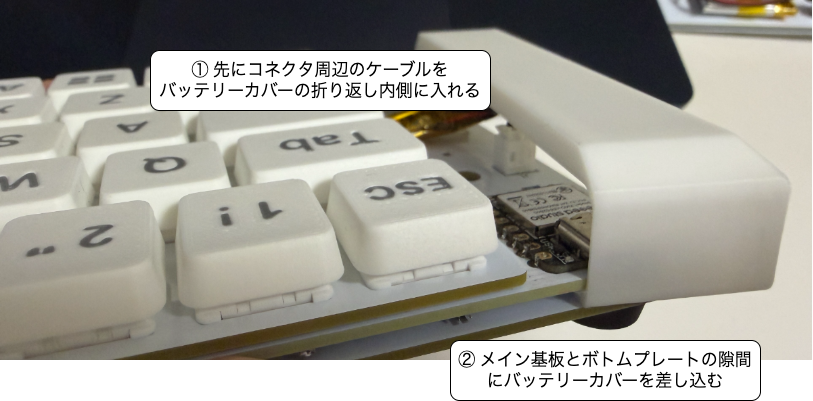
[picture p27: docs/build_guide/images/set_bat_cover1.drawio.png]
バッテリーカバーの取り付け方１


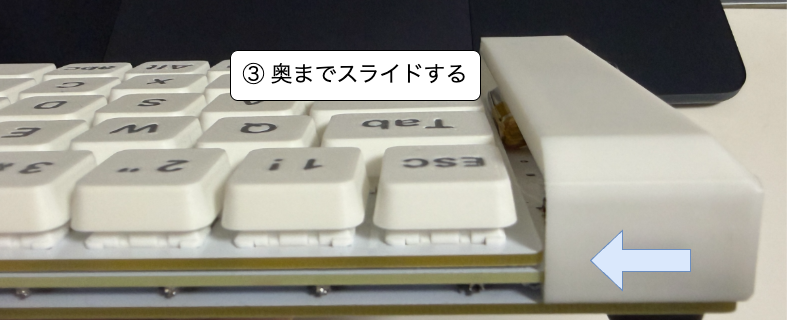
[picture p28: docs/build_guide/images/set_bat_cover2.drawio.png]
バッテリーカバーの取り付け方２


反対側も同様に取り付けます．

### 5.8 ゴム足・滑り止めの貼り付け

本キーボードは奥側（数字キー側）に高さのあるゴム足，手前側（スペースキー側）に高さのない滑り止めシートを貼り付けるのがオススメです．参考に使いやすい高さや滑り止め配置をカスタムしてみてください．

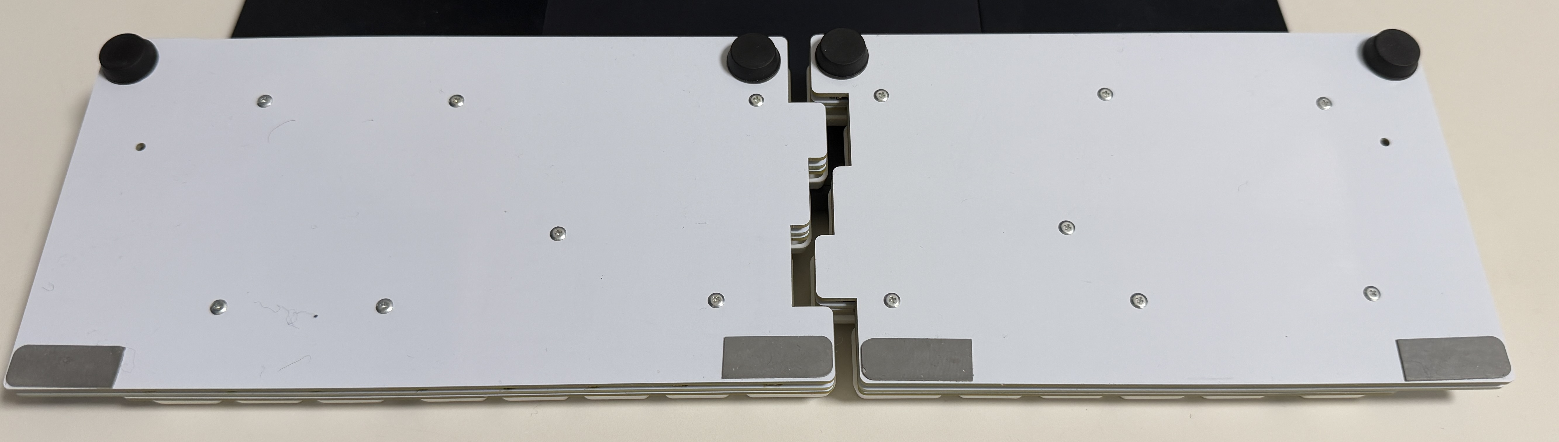
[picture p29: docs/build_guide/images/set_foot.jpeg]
ゴム足


### 5.9 組み立ての完成

これにて本体の組み立ては完成です！お疲れ様でした．

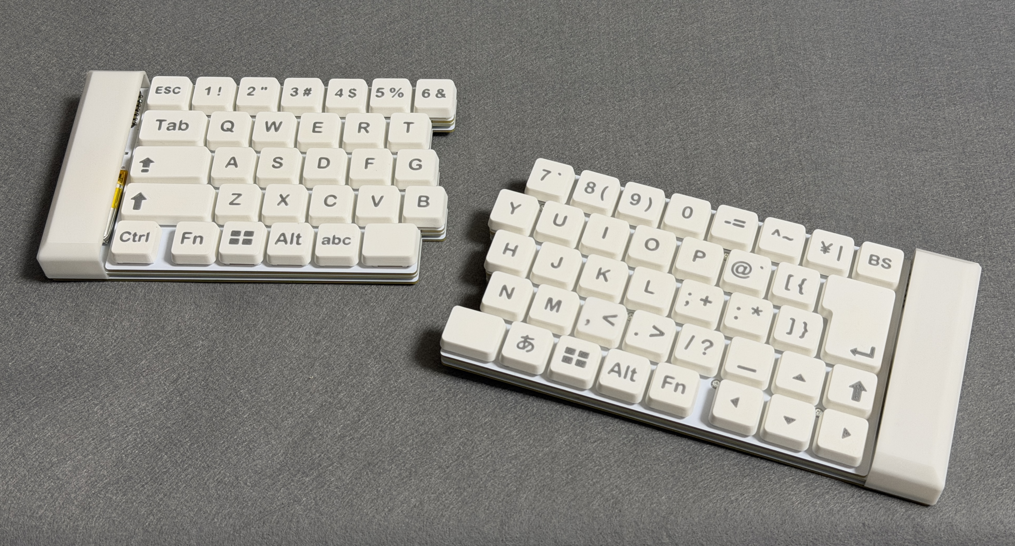
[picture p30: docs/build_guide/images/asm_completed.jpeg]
組み立て完了


## 6. ファームウェア（ZMK）

本キットのファームウェアは [ZMK Firmware](https://zmk.dev/docs) をベースに，本キーボード専用のシールドモジュール [b-sky-lab/tws_lp_shield_module](https://github.com/b-sky-lab/tws_lp_shield_module) として開発されています．

書き込みには次のものを用意してください．

- 組み立て済みの本体（左右）
- **データ通信に対応した** USBケーブル（充電専用ケーブルでは認識されません）
- パソコン

### 6.1 ファームウェア（uf2）の入手

コンパイル済みのファームウェアは [b-sky-lab/tws_lp_shield_module のリリースページ](https://github.com/b-sky-lab/tws_lp_shield_module/releases) から入手できます．最新リリースの Assets から，以下の3つのファイルをダウンロードしてください．

| ファイル名 | 用途 |
| --- | --- |
| `tws_lp_jis60_left.rgbled_adapter-seeeduino_xiao_ble-zmk.uf2` | 左手側（末梢）用 |
| `tws_lp_jis60_right.rgbled_adapter-seeeduino_xiao_ble-zmk.uf2` | 右手側（セントラル）用 |
| `settings_reset-seeeduino_xiao_ble-zmk.uf2` | 設定リセット用（6.3節で使用） |

> **注意**: 左手用・右手用でファイルが異なります．左右を取り違えると正しく動作しないため，書き込み時はファイル名をよく確認してください．
>
> 自分でキーマップをカスタムしてビルドしたい場合は，[b-sky-lab/tws_lp_shield_module](https://github.com/b-sky-lab/tws_lp_shield_module) リポジトリをforkしてご利用ください．

### 6.2 ファームウェアの書き込み

左右それぞれに，対応する uf2 ファイルを書き込みます．ここでは左手側を例に手順を示します．

1. **バッテリーカバーをスライドして取り外し**ます．ケーブルを破損しないよう注意しながら行ってください．
1. **USB接続**: 左手側本体の XIAO の USB ポートと，パソコンをケーブルで接続します．
1. **ブートローダーモードに入る**: XIAO のリセット（RST）ボタンを **2回素早く** 押します．成功すると XIAO 上の LED が点滅します．
1. **ドライブを確認する**: パソコンに `XIAO` で始まる名前のドライブ（USBストレージ）が現れます．
1. **uf2 をコピーする**: ダウンロードした **左手用** uf2 ファイル（`tws_lp_jis60_left...uf2`）を，`XIAO` ドライブにドラッグ＆ドロップでコピーします．
   - 書き込みは数秒〜10秒ほどで完了し，自動的にドライブが消えます．**コピー直後にドライブやファイルが消えるのは正常な動作**です（コピー失敗の警告が出ても無視して構いません）．
1. **右手側も同様に書き込む**: 右手側本体を接続し，同じ手順 1〜4 を **右手用** uf2 ファイル（`tws_lp_jis60_right...uf2`）で実行します．

### 6.3 設定のリセット

左右が接続できない，ペアリングがうまくいかないなど，Bluetooth まわりの動作が不安定な場合は，設定をリセットすると改善することがあります．

1. 左右それぞれを 6.2 と同じ手順でブートローダーモードに入れ，**設定リセット用** uf2 ファイル（`settings_reset...uf2`）を書き込みます．
1. 続けて，左右それぞれに **本番用** uf2 ファイル（左手用・右手用）を書き直します．
1. 右手側（セントラル）を先に電源 ON にして PC とペアリングし，接続を確認してから左手側の電源を ON にします．

## トラブルシューティング

組立中・組立後によくある症状と対処方法をまとめます．

### はんだ付け関連

#### 特定のキーが反応しない

最も多いトラブルです．次の順で原因を切り分けます．

1. **ホットスワップソケットの目視確認**: 該当キーのソケットが浮いていないか，はんだ付けに艶があるか
2. **ダイオードの極性確認**: 線（カソードバンド）の向きが他のダイオードと揃っているか
3. **ダイオードのはんだ付け確認**: 該当行・列の他のキーも反応しないかを確認（Charlieplexのため複数キーが連動する）
4. **スイッチ本体の不良**: 別のスイッチに差し替えてみる
5. **キーキャップが正しくセットされていない**: 押し下げきれていないケース

#### 複数のキーが同時に反応しない

Charlieplex方式では，特定のGPIOピンや配線で問題が起きると複数キーが連動して反応しなくなります．

- 反応しないキーをマトリクス上にマーキングしてみる
- 同じ列／行のキーが全滅していれば，その線につながる部品（ダイオードの片側，XIAOのピン周辺）を疑う
- XIAOのはんだ付けに不良がないか確認

#### キーが押しっぱなし扱いになる

- 該当キーのソケット内部にショートを引き起こす異物（はんだクズ・スイッチピンの曲がり）がないか確認
- 念のため，隣接キーのはんだブリッジも確認

### ファームウェア・BLE関連

#### PCに認識されない（ブートローダーモード）

XIAO がブートローダーモードに入らないと，uf2ファイルを書き込めません．

- リセットボタンを **2回素早く** 押せているか確認（1回押すだけだと通常リセット）
- USBケーブルが **データ通信対応** か確認（充電専用ケーブルでは認識されない）
- 別のUSBポートやケーブルで試す
- それでもダメな場合，XIAO本体の故障の可能性

#### 左右が繋がらない

セントラル（右手側）と末梢（左手側）の接続が確立しない場合の手順:

1. 両方の電源をOFF
2. 両方とも **設定リセット用uf2** を書き込み（6.3節参照）
3. 両方とも **本番用uf2** を書き直し
4. 右手側を先に電源ON，PCでペアリング
5. 右手側がPCに接続できたのを確認してから左手側を電源ON

#### PCに認識されない（BLE）

- 右手側の電池残量が十分か確認
- PCのBluetoothがONになっているか，機内モードでないか確認
- 過去のペアリング情報が残っていることがあるので，PC側からデバイスを一度削除して再ペアリング
- 右手側でプロファイル切替（`Fn + 1`）を試す

#### 入力が一部しかPCに送られない

- 左手側だけが反応しない → 左右の接続不良．8.2「左右が繋がらない」を参照
- 右手側だけが反応しない → 右手側はセントラルなので，通常は右が動かなければ左も動かない．プロファイル切替や再ペアリングを試す

### 入力品質関連

#### チャタリング（1回の打鍵が複数回入力される）

- ZMKのデバウンス設定を見直す（`CONFIG_ZMK_KSCAN_DEBOUNCE_PRESS_MS` / `CONFIG_ZMK_KSCAN_DEBOUNCE_RELEASE_MS`）
- スイッチ自体の不良の可能性．ホットスワップなので差し替えて検証

#### キー入力のもたつき・遅延

- 電池残量が極端に低い場合，BLE接続が不安定になることがある
- 他のBluetooth機器が近くで干渉している場合は離してみる
- 2.4GHz Wi-Fiルーターの近くではノイズで通信品質が落ちることがある

### 参考リンク

#### 本プロジェクト

- 設計リポジトリ: [b-sky-lab/tws_lp_jis60](https://github.com/b-sky-lab/tws_lp_jis60)
- ZMKシールドモジュール: [b-sky-lab/tws_lp_shield_module](https://github.com/b-sky-lab/tws_lp_shield_module)
- 設計者note: [JIS配列でロープロファイルな完全無線の左右分割キーボードを作った話](https://note.com/b_sky_lab/n/n9fbacc2c5264)
- 設計者X(Twitter): [@eternalfriend17](https://x.com/eternalfriend17)

#### インスパイア元・参考にした設計

- [sphh jp v2 (a bit keys)](https://abitkeys.com/sphhjp/build_v2.html)
- [自作キーボード設計ガイド (Salicylic-acid3)](https://salicylic-acid3.hatenablog.com/entry/guide1-introduction)

#### 使用部品・ファームウェア

- ZMK Firmware: [https://zmk.dev/docs](https://zmk.dev/docs)
- ZMK Studio: [https://zmk.studio/](https://zmk.studio/)
- XIAO nRF52840 (秋月電子): [https://akizukidenshi.com/catalog/g/g117341/](https://akizukidenshi.com/catalog/g/g117341/)
- Kailh White Rain スイッチ (遊舎工房): [https://shop.yushakobo.jp/products/9681](https://shop.yushakobo.jp/products/9681)
- zmk-rgbled-widget: [caksoylar/zmk-rgbled-widget](https://github.com/caksoylar/zmk-rgbled-widget)

### ライセンス・帰属

#### 本キット（tws_lp_jis60）

- ライセンス: **CC-BY-SA-4.0**（Creative Commons Attribution-ShareAlike 4.0 International）
- 詳細: [リポジトリのLICENSE](https://github.com/b-sky-lab/tws_lp_jis60/blob/main/LICENSE)

PCB設計データに OPL_Kicad_Library（CC-BY-SA-4.0）から派生したフットプリントが含まれるため，ShareAlike条項により本作も同ライセンスを継承しています．

#### 第三者ライブラリ

本キットの設計データには次のライブラリを利用しています．詳細はリポジトリREADMEを参照してください．

- [OPL_Kicad_Library](https://github.com/Seeed-Studio/OPL_Kicad_Library) — CC-BY-SA-4.0
- [KiCAD_FootPrint (Salicylic-acid3)](https://github.com/Salicylic-acid3/KiCAD_FootPrint) — MIT
- [MX_V2 (ai03-2725)](https://github.com/ai03-2725/MX_V2) — MIT

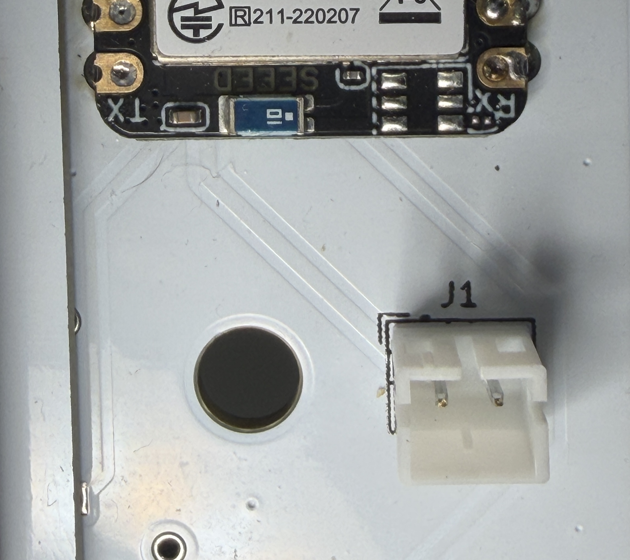
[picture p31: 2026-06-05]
docs/build_guide/images/ph_direction_after.jpeg

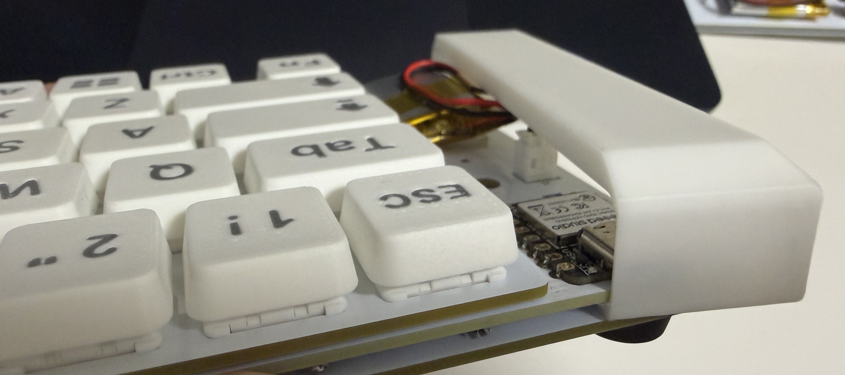
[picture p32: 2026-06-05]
docs/build_guide/images/set_bat_cover1.jpeg

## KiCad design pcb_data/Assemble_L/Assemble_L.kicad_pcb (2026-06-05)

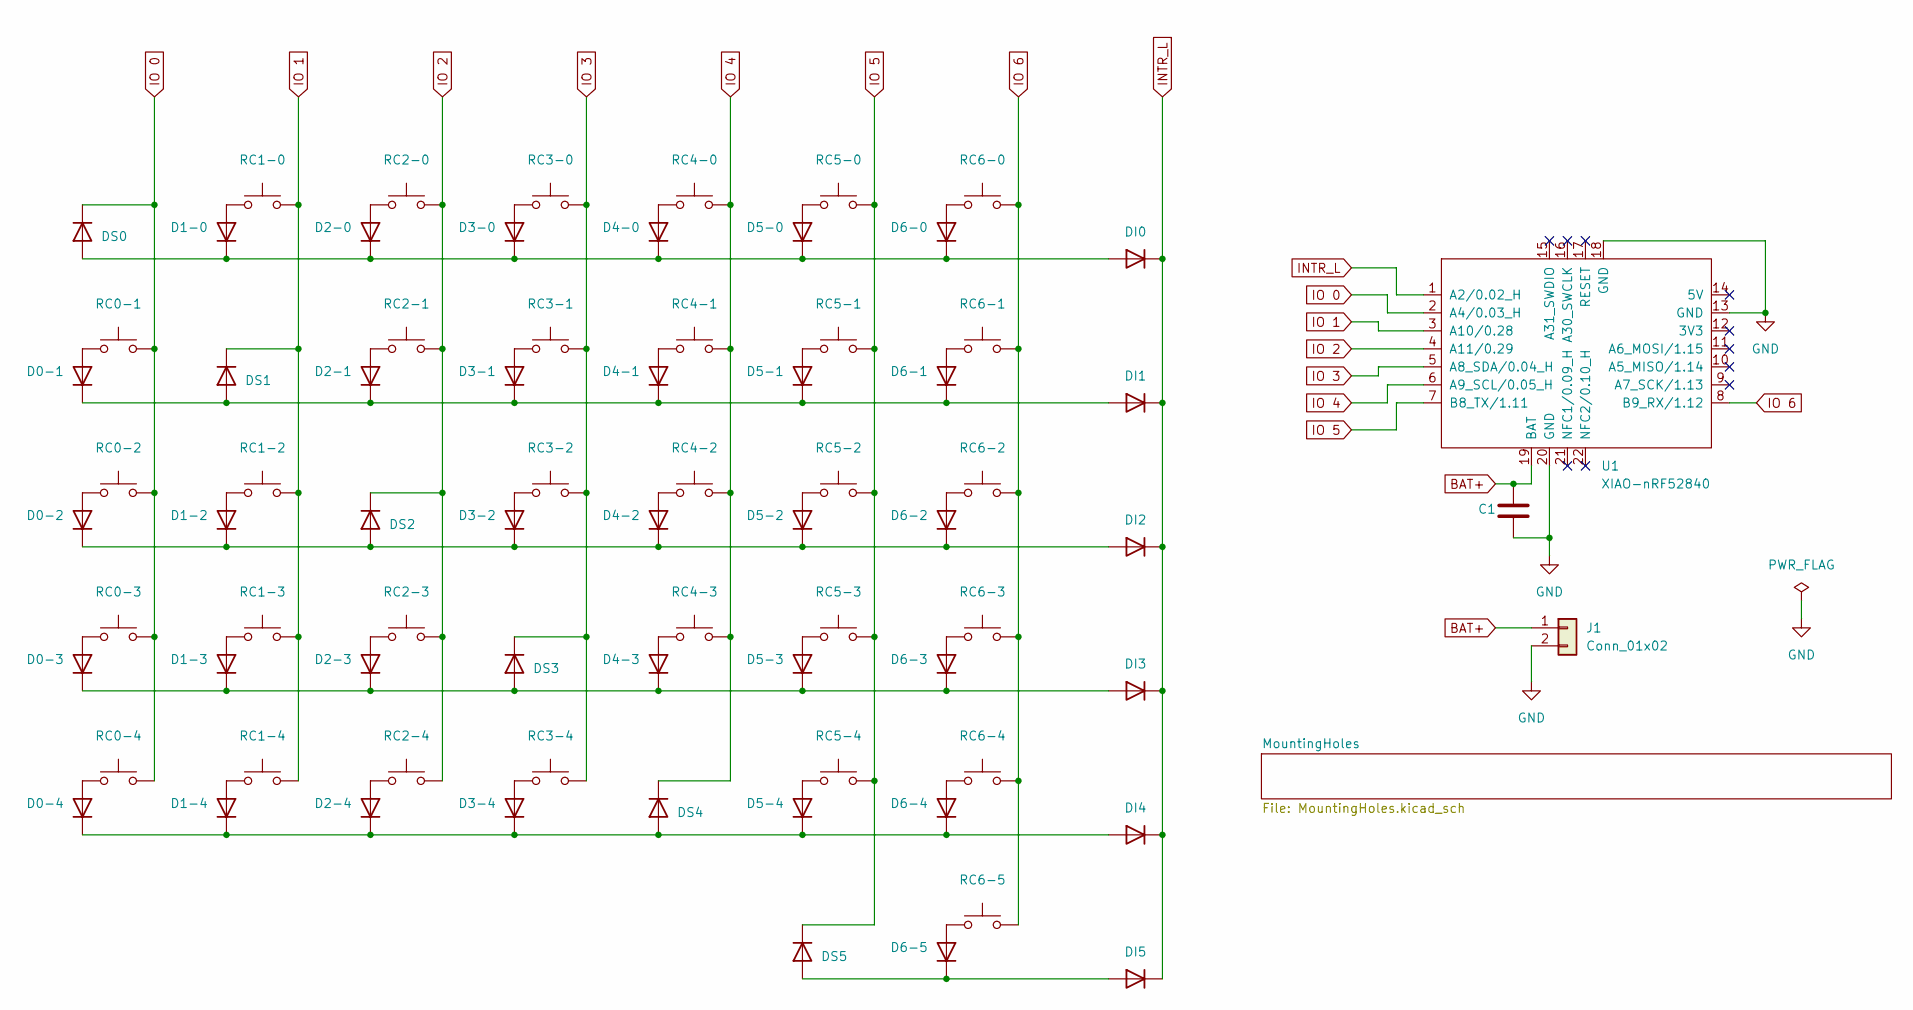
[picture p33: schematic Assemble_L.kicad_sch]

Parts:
C1: GRM32EC81C476KE15L; C_1210_3225Metric_Pad1.33x2.70mm_HandSolder
D0-1, D0-2, D0-3, D0-4, D1-0, D1-2, D1-3, D1-4, D2-0, D2-1, D2-3, D2-4, D3-0, D3-1, D3-2, D3-4, D4-0, D4-1, D4-2, D4-3, D5-0, D5-1, D5-2, D5-3, D5-4, D6-0, D6-1, D6-2, D6-3, D6-4, D6-5: 1N4148W; Diode_TH_SMD
DI0, DI1, DI2, DI3, DI4, DI5: 1N4148W; Diode_TH_SMD
DS0, DS1, DS2, DS3, DS4, DS5: 1N4148W; Diode_TH_SMD
J1: Conn_01x02; JST_PH_B2B-PH-K_1x02_P2.00mm_Vertical
RC0-1: SW_Push; Kailh-PG1353-Hotswap-L-1.5U
RC0-2: SW_Push; Kailh-PG1353-Hotswap-L-1.75U
RC0-3: SW_Push; Kailh-PG1353-Hotswap-L-2U
RC0-4, RC1-0, RC1-2, RC1-3, RC1-4, RC2-0, RC2-1, RC2-3, RC2-4, RC3-0, RC3-1, RC3-2, RC3-4, RC4-0, RC4-1, RC4-2, RC4-3, RC5-0, RC5-1, RC5-2, RC5-3, RC5-4, RC6-0, RC6-1, RC6-2, RC6-3, RC6-4: SW_Push; Kailh-PG1353-Hotswap-L-1U
RC6-5: SW_Push; Kailh-PG1353-Hotswap-L-1.25U
U1: XIAO-nRF52840; xiao-ble-smd-cutout

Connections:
BAT+: C1.1, J1.1, U1.19 (BAT)
GND: C1.2, J1.2, U1.13 (GND), U1.18 (GND), U1.20 (GND)
INTR_L: DI0.1 (K), DI1.1 (K), DI2.1 (K), DI3.1 (K), DI4.1 (K), DI5.1 (K), U1.1 (A2/0.02_H)
IO 0: DS0.1 (K), RC0-1.1, RC0-2.1, RC0-3.1, RC0-4.1, U1.2 (A4/0.03_H)
IO 1: DS1.1 (K), RC1-0.1, RC1-2.1, RC1-3.1, RC1-4.1, U1.3 (A10/0.28)
IO 2: DS2.1 (K), RC2-0.1, RC2-1.1, RC2-3.1, RC2-4.1, U1.4 (A11/0.29)
IO 3: DS3.1 (K), RC3-0.1, RC3-1.1, RC3-2.1, RC3-4.1, U1.5 (A8_SDA/0.04_H)
IO 4: DS4.1 (K), RC4-0.1, RC4-1.1, RC4-2.1, RC4-3.1, U1.6 (A9_SCL/0.05_H)
IO 5: DS5.1 (K), RC5-0.1, RC5-1.1, RC5-2.1, RC5-3.1, RC5-4.1, U1.7 (B8_TX/1.11)
IO 6: RC6-0.1, RC6-1.1, RC6-2.1, RC6-3.1, RC6-4.1, RC6-5.1, U1.8 (B9_RX/1.12)
unnamed: D0-1.2 (A), RC0-1.2
unnamed: D0-1.1 (K), D2-1.1 (K), D3-1.1 (K), D4-1.1 (K), D5-1.1 (K), D6-1.1 (K), DI1.2 (A), DS1.2 (A)
unnamed: D0-2.2 (A), RC0-2.2
unnamed: D0-2.1 (K), D1-2.1 (K), D3-2.1 (K), D4-2.1 (K), D5-2.1 (K), D6-2.1 (K), DI2.2 (A), DS2.2 (A)
unnamed: D0-3.2 (A), RC0-3.2
unnamed: D0-3.1 (K), D1-3.1 (K), D2-3.1 (K), D4-3.1 (K), D5-3.1 (K), D6-3.1 (K), DI3.2 (A), DS3.2 (A)
unnamed: D0-4.2 (A), RC0-4.2
unnamed: D0-4.1 (K), D1-4.1 (K), D2-4.1 (K), D3-4.1 (K), D5-4.1 (K), D6-4.1 (K), DI4.2 (A), DS4.2 (A)
unnamed: D1-0.2 (A), RC1-0.2
unnamed: D1-0.1 (K), D2-0.1 (K), D3-0.1 (K), D4-0.1 (K), D5-0.1 (K), D6-0.1 (K), DI0.2 (A), DS0.2 (A)
unnamed: D1-2.2 (A), RC1-2.2
unnamed: D1-3.2 (A), RC1-3.2
unnamed: D1-4.2 (A), RC1-4.2
unnamed: D2-0.2 (A), RC2-0.2
unnamed: D2-1.2 (A), RC2-1.2
unnamed: D2-3.2 (A), RC2-3.2
unnamed: D2-4.2 (A), RC2-4.2
unnamed: D3-0.2 (A), RC3-0.2
unnamed: D3-1.2 (A), RC3-1.2
unnamed: D3-2.2 (A), RC3-2.2
unnamed: D3-4.2 (A), RC3-4.2
unnamed: D4-0.2 (A), RC4-0.2
unnamed: D4-1.2 (A), RC4-1.2
unnamed: D4-2.2 (A), RC4-2.2
unnamed: D4-3.2 (A), RC4-3.2
unnamed: D5-0.2 (A), RC5-0.2
unnamed: D5-1.2 (A), RC5-1.2
unnamed: D5-2.2 (A), RC5-2.2
unnamed: D5-3.2 (A), RC5-3.2
unnamed: D5-4.2 (A), RC5-4.2
unnamed: D6-0.2 (A), RC6-0.2
unnamed: D6-1.2 (A), RC6-1.2
unnamed: D6-2.2 (A), RC6-2.2
unnamed: D6-3.2 (A), RC6-3.2
unnamed: D6-4.2 (A), RC6-4.2
unnamed: D6-5.2 (A), RC6-5.2
unnamed: D6-5.1 (K), DI5.2 (A), DS5.2 (A)

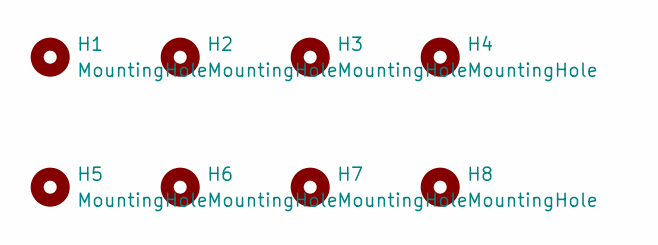
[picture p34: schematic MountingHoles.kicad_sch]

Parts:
H1, H2, H3, H4, H5, H6, H7, H8: MountingHole; m2_Spacer_Hole

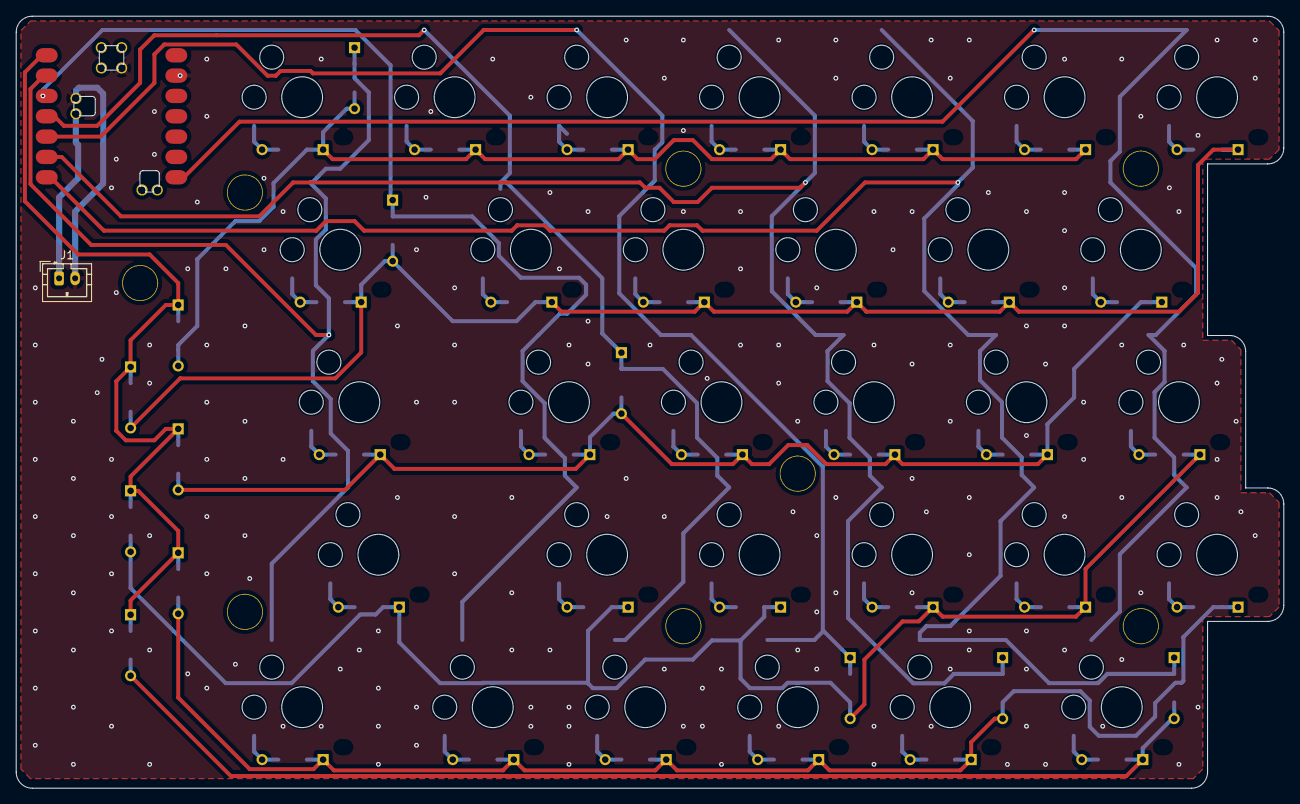
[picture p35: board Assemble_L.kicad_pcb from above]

Board: 2 copper layers, 158.4 x 96.4 mm, 85 parts (1 on the bottom side), 47 nets.

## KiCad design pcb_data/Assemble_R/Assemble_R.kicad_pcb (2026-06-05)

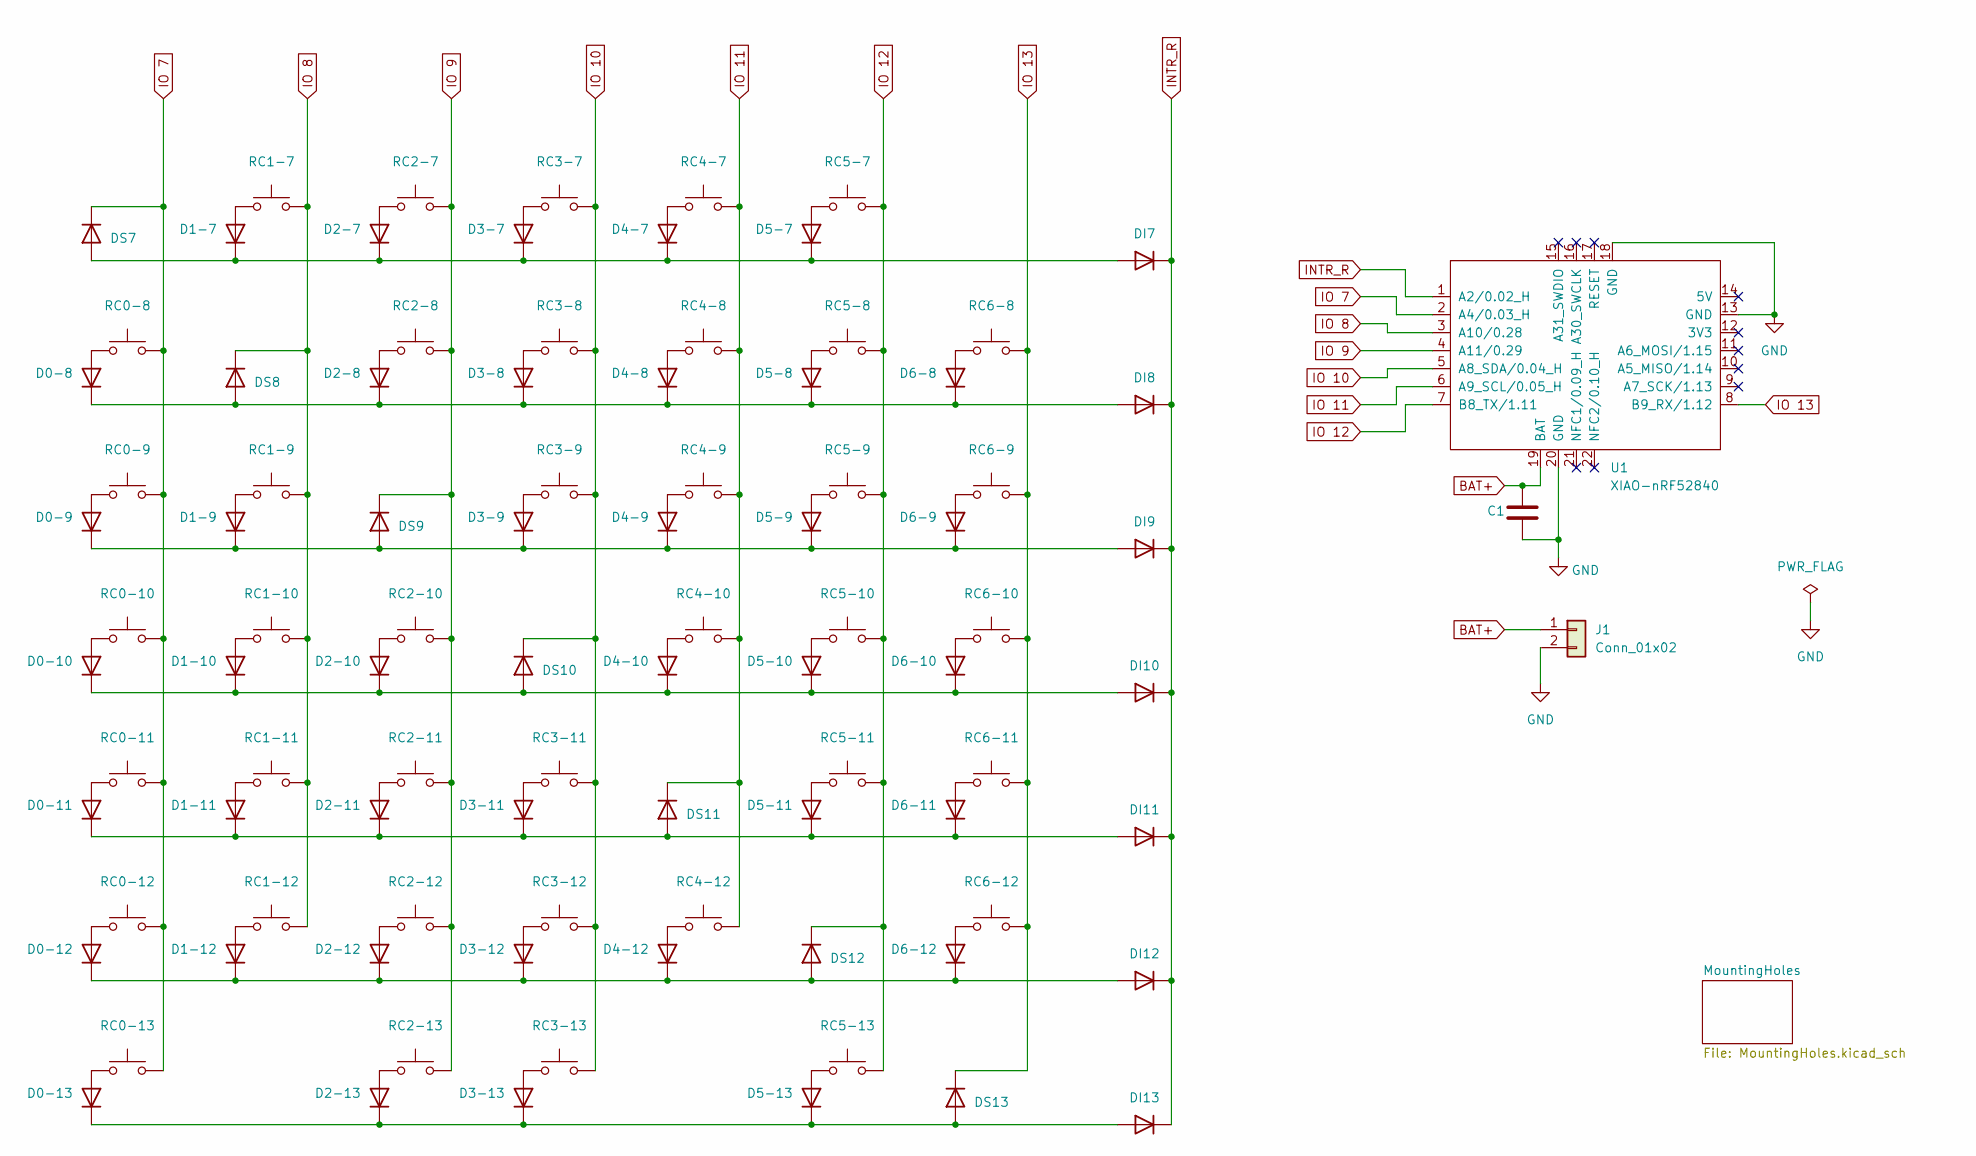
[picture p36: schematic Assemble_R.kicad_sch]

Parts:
C1: GRM32EC81C476KE15L; C_1210_3225Metric_Pad1.33x2.70mm_HandSolder
D0-8, D0-9, D0-10, D0-11, D0-12, D0-13, D1-7, D1-9, D1-10, D1-11, D1-12, D2-7, D2-8, D2-10, D2-11, D2-12, D2-13, D3-7, D3-8, D3-9, D3-11, D3-12, D3-13, D4-7, D4-8, D4-9, D4-10, D4-12, D5-7, D5-8, D5-9, D5-10, D5-11, D5-13, D6-8, D6-9, D6-10, D6-11, D6-12: 1N4148W; Diode_TH_SMD
DI7, DI8, DI9, DI10, DI11, DI12, DI13: 1N4148W; Diode_TH_SMD
DS7, DS8, DS9, DS10, DS11, DS12, DS13: 1N4148W; Diode_TH_SMD
J1: Conn_01x02; JST_PH_B2B-PH-K_1x02_P2.00mm_Vertical
RC0-8, RC0-9, RC0-10, RC0-11, RC0-12, RC1-7, RC1-9, RC1-10, RC1-11, RC1-12, RC2-7, RC2-8, RC2-10, RC2-11, RC2-12, RC2-13, RC3-7, RC3-8, RC3-9, RC3-11, RC3-12, RC3-13, RC4-7, RC4-8, RC4-9, RC4-10, RC4-12, RC5-7, RC5-8, RC5-9, RC5-10, RC5-11, RC5-13, RC6-8, RC6-9, RC6-11, RC6-12: SW_Push; Kailh-PG1353-Hotswap-R-1U
RC0-13: SW_Push; Kailh-PG1353-Hotswap-R-1.25U
RC6-10: SW_Push; Kailh-PG1353-Hotswap-ISOEnter-R
U1: XIAO-nRF52840; xiao-ble-smd-cutout

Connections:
BAT+: C1.1, J1.1, U1.19 (BAT)
GND: C1.2, J1.2, U1.13 (GND), U1.18 (GND), U1.20 (GND)
INTR_R: DI7.1 (K), DI8.1 (K), DI9.1 (K), DI10.1 (K), DI11.1 (K), DI12.1 (K), DI13.1 (K), U1.1 (A2/0.02_H)
IO 7: DS7.1 (K), RC0-8.1, RC0-9.1, RC0-10.1, RC0-11.1, RC0-12.1, RC0-13.1, U1.2 (A4/0.03_H)
IO 8: DS8.1 (K), RC1-7.1, RC1-9.1, RC1-10.1, RC1-11.1, RC1-12.1, U1.3 (A10/0.28)
IO 9: DS9.1 (K), RC2-7.1, RC2-8.1, RC2-10.1, RC2-11.1, RC2-12.1, RC2-13.1, U1.4 (A11/0.29)
IO 10: DS10.1 (K), RC3-7.1, RC3-8.1, RC3-9.1, RC3-11.1, RC3-12.1, RC3-13.1, U1.5 (A8_SDA/0.04_H)
IO 11: DS11.1 (K), RC4-7.1, RC4-8.1, RC4-9.1, RC4-10.1, RC4-12.1, U1.6 (A9_SCL/0.05_H)
IO 12: DS12.1 (K), RC5-7.1, RC5-8.1, RC5-9.1, RC5-10.1, RC5-11.1, RC5-13.1, U1.7 (B8_TX/1.11)
IO 13: DS13.1 (K), RC6-8.1, RC6-9.1, RC6-10.1, RC6-11.1, RC6-12.1, U1.8 (B9_RX/1.12)
unnamed: D0-8.2 (A), RC0-8.2
unnamed: D0-8.1 (K), D2-8.1 (K), D3-8.1 (K), D4-8.1 (K), D5-8.1 (K), D6-8.1 (K), DI8.2 (A), DS8.2 (A)
unnamed: D0-9.2 (A), RC0-9.2
unnamed: D0-9.1 (K), D1-9.1 (K), D3-9.1 (K), D4-9.1 (K), D5-9.1 (K), D6-9.1 (K), DI9.2 (A), DS9.2 (A)
unnamed: D0-10.2 (A), RC0-10.2
unnamed: D0-10.1 (K), D1-10.1 (K), D2-10.1 (K), D4-10.1 (K), D5-10.1 (K), D6-10.1 (K), DI10.2 (A), DS10.2 (A)
unnamed: D0-11.2 (A), RC0-11.2
unnamed: D0-11.1 (K), D1-11.1 (K), D2-11.1 (K), D3-11.1 (K), D5-11.1 (K), D6-11.1 (K), DI11.2 (A), DS11.2 (A)
unnamed: D0-12.2 (A), RC0-12.2
unnamed: D0-12.1 (K), D1-12.1 (K), D2-12.1 (K), D3-12.1 (K), D4-12.1 (K), D6-12.1 (K), DI12.2 (A), DS12.2 (A)
unnamed: D0-13.2 (A), RC0-13.2
unnamed: D0-13.1 (K), D2-13.1 (K), D3-13.1 (K), D5-13.1 (K), DI13.2 (A), DS13.2 (A)
unnamed: D1-7.2 (A), RC1-7.2
unnamed: D1-7.1 (K), D2-7.1 (K), D3-7.1 (K), D4-7.1 (K), D5-7.1 (K), DI7.2 (A), DS7.2 (A)
unnamed: D1-9.2 (A), RC1-9.2
unnamed: D1-10.2 (A), RC1-10.2
unnamed: D1-11.2 (A), RC1-11.2
unnamed: D1-12.2 (A), RC1-12.2
unnamed: D2-7.2 (A), RC2-7.2
unnamed: D2-8.2 (A), RC2-8.2
unnamed: D2-10.2 (A), RC2-10.2
unnamed: D2-11.2 (A), RC2-11.2
unnamed: D2-12.2 (A), RC2-12.2
unnamed: D2-13.2 (A), RC2-13.2
unnamed: D3-7.2 (A), RC3-7.2
unnamed: D3-8.2 (A), RC3-8.2
unnamed: D3-9.2 (A), RC3-9.2
unnamed: D3-11.2 (A), RC3-11.2
unnamed: D3-12.2 (A), RC3-12.2
unnamed: D3-13.2 (A), RC3-13.2
unnamed: D4-7.2 (A), RC4-7.2
unnamed: D4-8.2 (A), RC4-8.2
unnamed: D4-9.2 (A), RC4-9.2
unnamed: D4-10.2 (A), RC4-10.2
unnamed: D4-12.2 (A), RC4-12.2
unnamed: D5-7.2 (A), RC5-7.2
unnamed: D5-8.2 (A), RC5-8.2
unnamed: D5-9.2 (A), RC5-9.2
unnamed: D5-10.2 (A), RC5-10.2
unnamed: D5-11.2 (A), RC5-11.2
unnamed: D5-13.2 (A), RC5-13.2
unnamed: D6-8.2 (A), RC6-8.2
unnamed: D6-9.2 (A), RC6-9.2
unnamed: D6-10.2 (A), RC6-10.2
unnamed: D6-11.2 (A), RC6-11.2
unnamed: D6-12.2 (A), RC6-12.2


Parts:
H1, H2, H3, H4, H5, H6, H7, H8: MountingHole; m2_Spacer_Hole

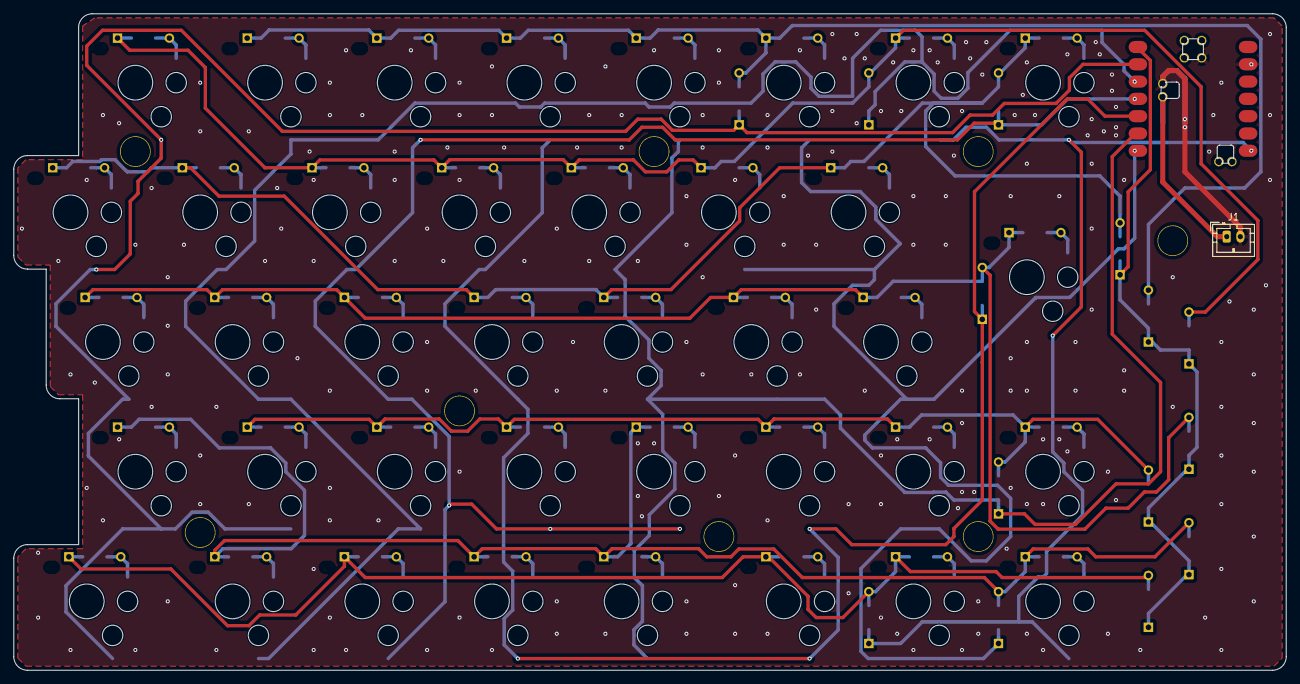
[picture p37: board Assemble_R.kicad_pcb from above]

Board: 2 copper layers, 186.9 x 96.4 mm, 103 parts (1 on the bottom side), 56 nets.

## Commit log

2025-12-17 Feat/add kicad pro (#4)
    * add .gitignore
    * Add submodule: OPL_Kicad_Library
    * Add submodule: MX_V2
    * Add submodule: KiCAD_FootPrint
    * update .gitignore
    * add keyboard layout file
    * add custom fp
    * add kicad file
    * complete to design pattern of board L
    * Update submodules: resolve DRC warning about silk
    * Update submodule URLs to kim-xps12 forks
    * fix line width 0.2 -> 0.5
    * add GND plane
    * complete to design pattern of board R
    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
    [Assemble_L.kicad_pcb, Assemble_L.kicad_sch, Assemble_L.step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]
2025-12-17 add mount hole (#5)
    ネジ穴を追加しました．
    特にレビュー項目はない（git logを綺麗に残すためのPR）のでセルフマージします．
    [Assemble_L.kicad_pcb, Assemble_R.kicad_pcb]
2025-12-17 Feat/add plugin for jlcpcb (#6)
    * add mount hole
    * add plugin for jlcpcb
    * add production.zip
    [Assemble_L-B_Cu.gbl, Assemble_L-B_Mask.gbs, Assemble_L-B_Paste.gbp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]
2025-12-30 update .gitignore (#7)
    [Assemble_L-B_Cu.gbl, Assemble_L-B_Mask.gbs, Assemble_L-B_Paste.gbp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]
2025-12-30 add xiao-ble library for cut hole
2025-12-30 replace footprint of xiao-nrf52840
    [Assemble_R.kicad_pcb, Assemble_R.kicad_sch]
2025-12-30 Update KiCAD_FootPrint submodule to kim-xps12 fork
2025-12-30 add GND beta
    [Assemble_R.kicad_pcb]
2025-12-30 replace symbol of xiao-ble
    [Assemble_L.kicad_sch, Assemble_R.kicad_sch]
2026-06-05 Develop (#31)
    * Feat/add kicad pro (#4)
    * add README and LICENCE of custom footprint
    * delete unnecessary third-party library
    * update foot print reference, and fix GND filling area DRC error
    * add 3d model
    * add licence details (#3)
    マージして閉じます
    ---------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
    [Assemble_L.kicad_pcb, Assemble_L.kicad_sch, Assemble_L.step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]
2026-06-05 リポジトリ移管に伴い公開URLをkim-xps12へ更新 (#32)
    所有権が ar-kr から kim-xps12 へ移管されたため,
    README のビルドガイド公開URLを kim-xps12.github.io へ修正する.
    併せて以下のリポジトリ設定を変更済み（コミット対象外）:
    - git remote origin を kim-xps12/tws_lp_jis60 へ変更
    - GitHub Pages の Source を「GitHub Actions」へ設定
2026-06-05 ビルドガイドをAstro Starlightへ移行 (#33)
    * ビルドガイドの公開基盤をMkDocsからAstro Starlightへ移行
    見た目の刷新と画像最適化のため、静的サイト生成を MkDocs Material から
    Astro Starlight へ置き換える。build_guide.md は唯一のソースとして変更せず、
    ビルド時に scripts/sync-content.mjs が Starlight 用へ自動変換する
    （frontmatter付与・H1のtitle昇格・GFMアラート→アサイド変換・画像パス正規化）。
    - 追加: package.json / package-lock.json / astro.config.mjs / tsconfig.json
    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
2026-06-05 Feat/update readme (#34)
    * ファームウェアのリポジトリURLを修正
    * 完成品の写真をREADMEにも追加
2026-06-05 chore: リポジトリ移管に伴い公開URLをb-sky-lab orgへ更新 (#35)
    * chore: リポジトリ移管に伴い公開URLをb-sky-lab orgへ更新
    kim-xps12個人リポジトリからb-sky-lab organizationへの移管に伴い、
    公開URLとリポジトリリンクを更新する。
    - astro.config.mjs: GitHub Pages site/GitHubリンクをb-sky-labへ
    - README.md: ビルドガイドWeb版URLとファームウェアリポジトリ
    (tws_lp_shield_module)のリンクをb-sky-labへ
    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
2026-06-05 docs: ビルドガイドのタイトル表記を Tws-lp-jis60 に統一 (#36)
    サイトタイトル・H1見出し・各種 description の表示名を
    tws_lp_jis60 から Tws-lp-jis60 へ変更。リポジトリ/パッケージ
    スラッグやファイル名などの識別子はそのまま維持。
2026-06-05 完成写真をビルドガイドのトップへ移動 (#37)
2026-06-05 バッテリーカバーの注釈を追記
